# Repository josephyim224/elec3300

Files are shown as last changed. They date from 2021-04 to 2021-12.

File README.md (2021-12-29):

# Elec3300

This project builds an omni wheel car with a bluetooth remote controller. The omni wheel robot is based on STM32F103 with DRV8801 as motor driver. The controller is based on STM8S003.

## Car

### PCB Design

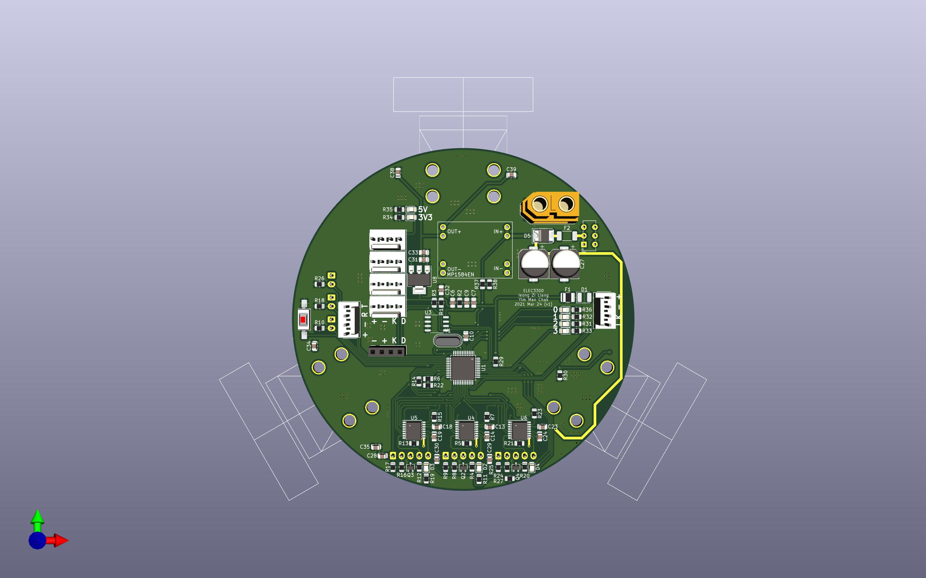
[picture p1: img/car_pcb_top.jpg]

*Car PCB Top View*

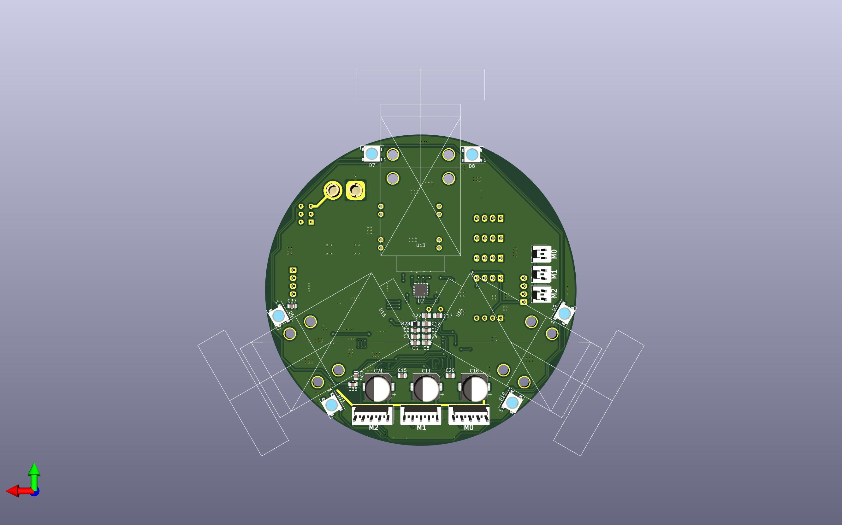
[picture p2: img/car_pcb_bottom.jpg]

*Car PCB Bottom View*

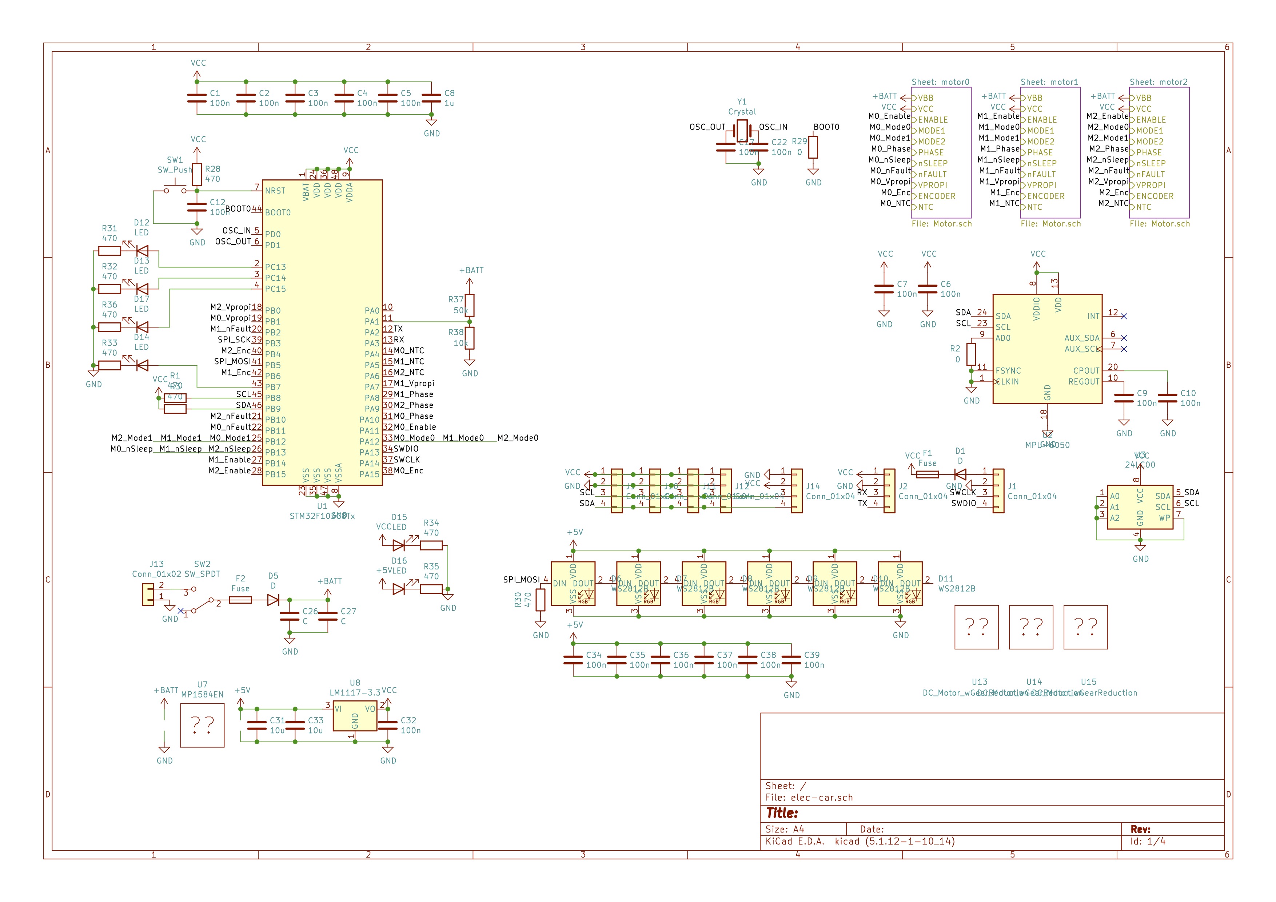
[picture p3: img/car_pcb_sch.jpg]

*see [schematic.pdf](car_hw/output/schematic.pdf)*

### 3D Print Components

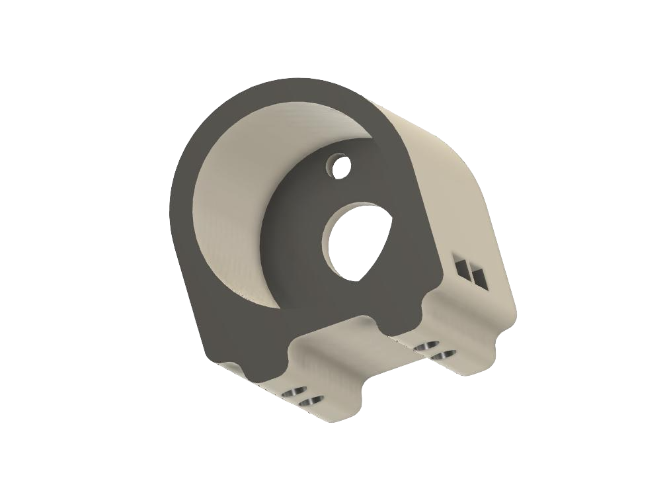
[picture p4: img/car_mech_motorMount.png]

*Car Motor Mount*

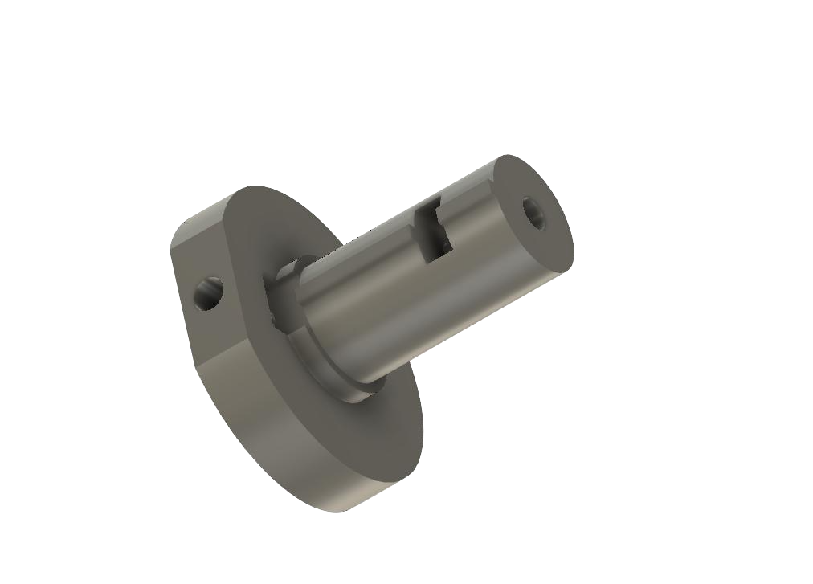
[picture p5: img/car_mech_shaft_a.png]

*Car Shaft A*

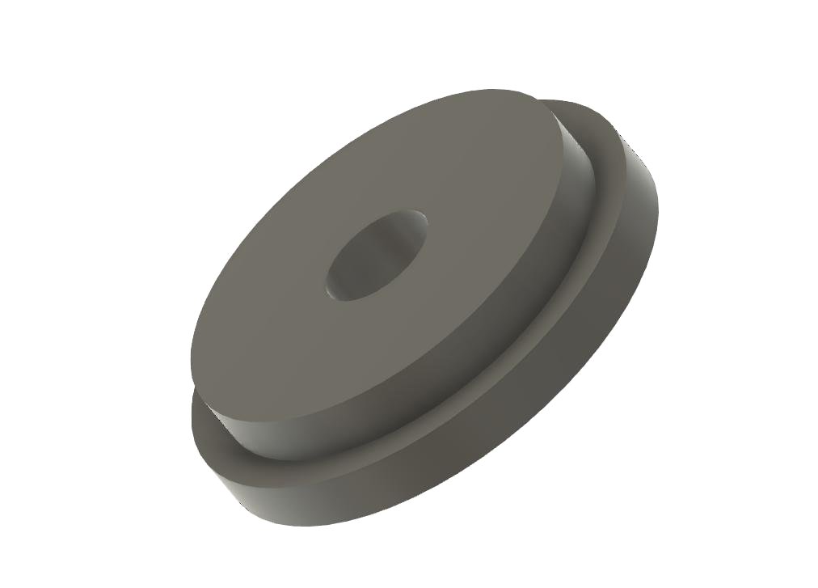
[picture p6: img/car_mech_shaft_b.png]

*Car Shaft B*

### Software

- Use STM32CubeIDE
- Refer to `/car_sw`

## Remote

### PCB Design

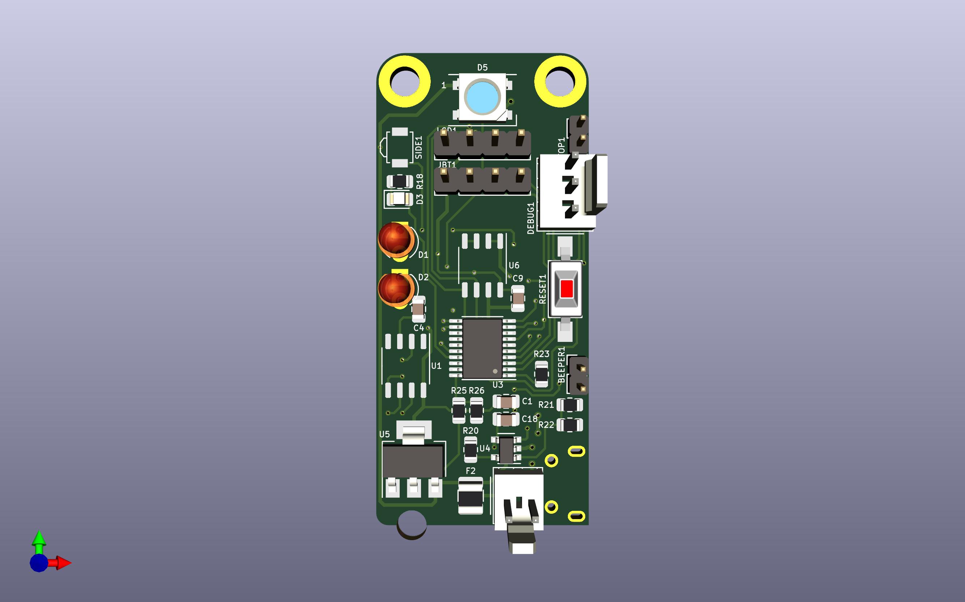
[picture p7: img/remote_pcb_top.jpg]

*Remote PCB Top View*

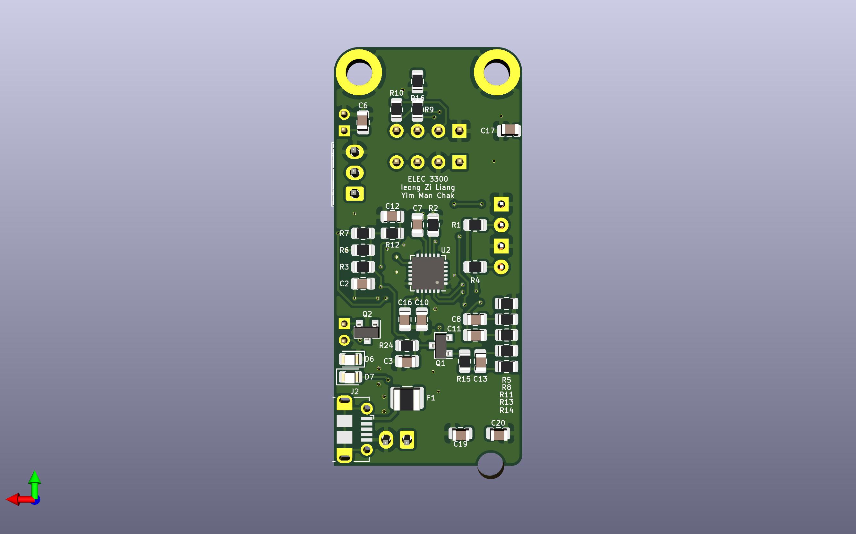
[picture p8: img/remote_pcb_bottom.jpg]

*Remote PCB Bottom View*

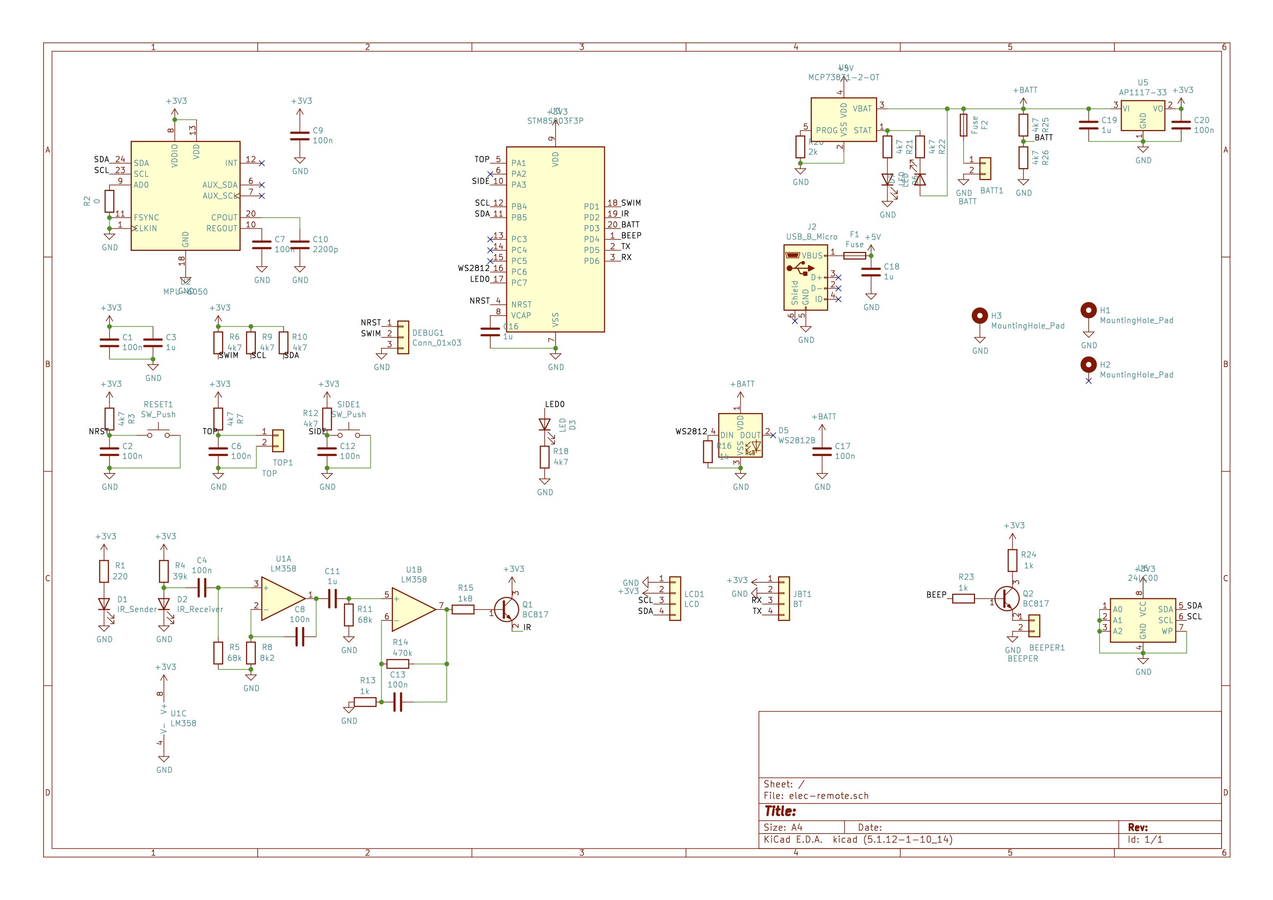
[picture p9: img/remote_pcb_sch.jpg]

*see [schematic.pdf](remote_hw/output/schematic.pdf)*

### 3D Print Components

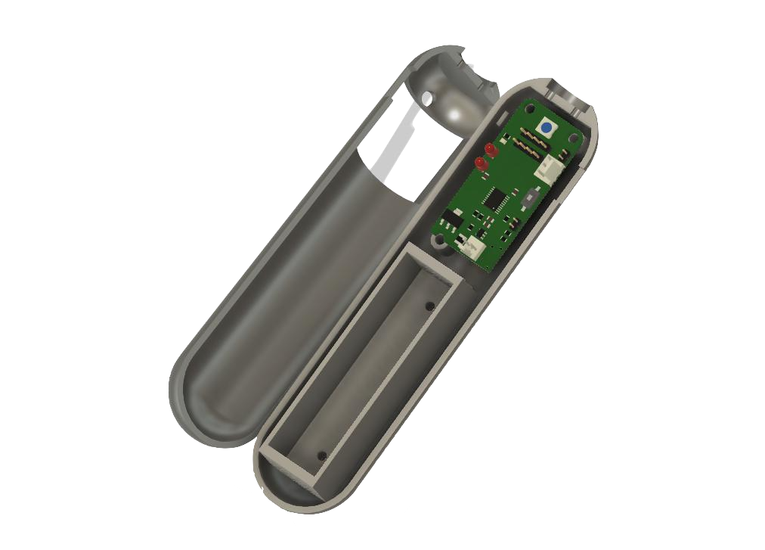
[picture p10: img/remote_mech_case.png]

*Remote Case*

### Software

Setup:
1. `sudo apt-get install libusb-1.0-0-dev sdcc -y`
1. Get [stm8flash](https://github.com/vdudouyt/stm8flash)
1. Run `bash ./flash.sh` to compile and flash program

Reference: [Getting started with STM8 Development Tools on GNU/LINUX](https://www.codementor.io/@hbendali/)getting-started-with-stm8-development-tools-on-gnu-linux-zu59yo35x

Template: [stsw-stm8069](https://my.st.com/content/my_st_com/en/products/embedded-software/mcu-mpu-embedded-software/stm8-embedded-software/stsw-stm8069.html)

Library: [stm8s-sdcc](https://github.com/stecman/stm8s-sdcc)

## Final Deliverables
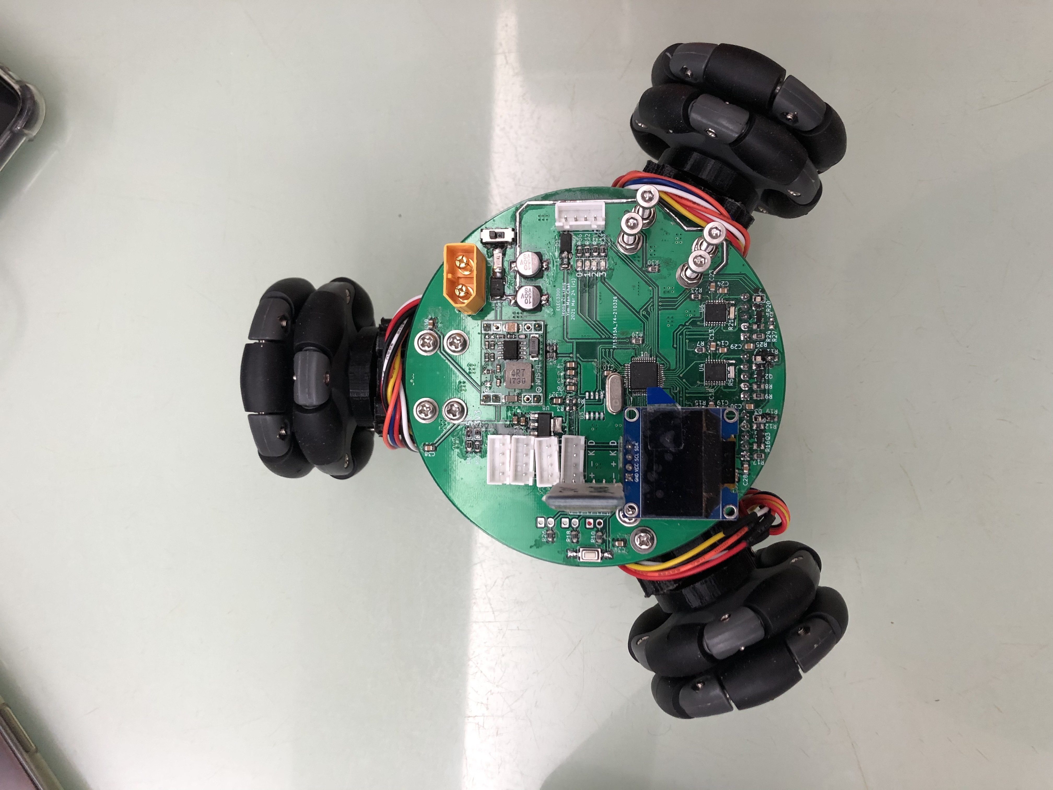
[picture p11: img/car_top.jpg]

*Car Top*

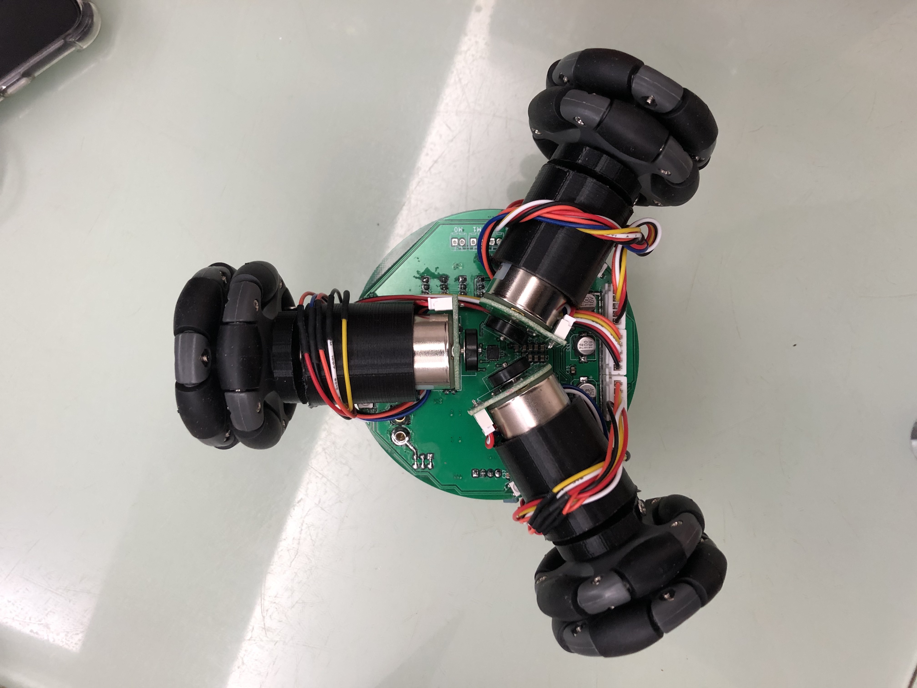
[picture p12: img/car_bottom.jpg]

*Car Bottom*

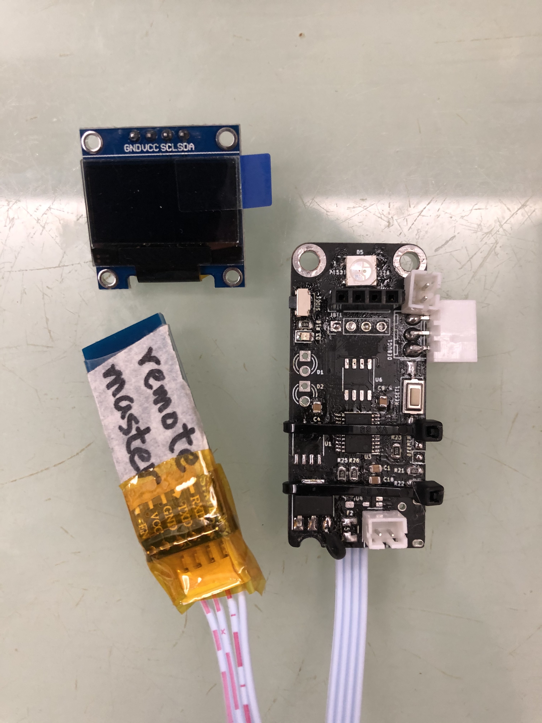
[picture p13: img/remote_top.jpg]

*Remote Top*

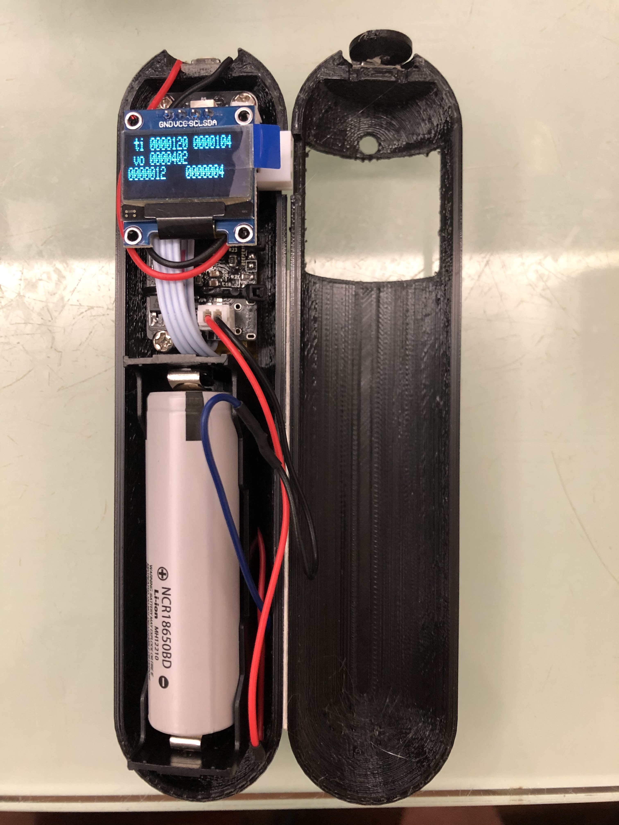
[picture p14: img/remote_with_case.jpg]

*Remote With Case*

## Progress
| urgency | difficulty | task | description | done? |
| --- | --- | --- | --- | --- |
| - | - | design pcb | | v |
| - | - | solder pcb | | v |
| - | - | mech design | | car(v), remote(v) |
| 0 | 0 | button | button | remote(v) | |
| 0 | 0 | led | led display | car(v), remote(v) |
| 1 | 1 | motor driver | (car) pwm & direction control | v |
| 1 | 2 | uart | communicate | car(v), remote(v) |
| 1 | 2 | i2c | communicate | car(v hardware), remote(v software) |
| 1 | 3 | mpu6050 (i2c) | port and simplify Adafruit version | car(v), remote(v) |
| 2 | 4 | ssd1306 lcd (i2c) | display line and text | car(v), remote(v) |
| 3 | 2 | ws2812b RGB led | display R/G/B | car(v), remote(x) |
| 4 | 1 | vibration motor | (remote) pwm output | x |
| 4 | 2 | 24c02 eeprom (i2c) | read and write data | x |
| 4 | ? | encoder | (car) encoder counter | v |
| 5 | 4 | gy530 TOF (i2c) | get distance | x |

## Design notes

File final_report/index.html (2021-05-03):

ELEC 3300 Final Project

Title : Reinventing remote robot with 3D input

Group: 10

Members Name | Ieong, Zi Liang Jason | Yim Man Chak
Members Email | zljieong@ust.hk | mcyim@ust.hk

Project Summary

Proposal Presentation

Proposal Presentation Video (https://youtu.be/K2rHprsLhMI)

Project Final Presentation

Project Final Demo and Presentation Video (https://youtu.be/Ji7nnWsCJ6Y)

Photos

Remote | Car
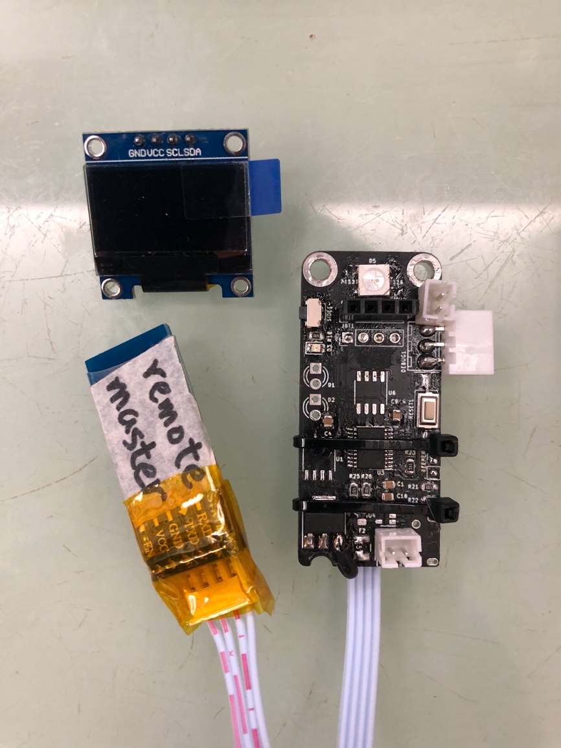
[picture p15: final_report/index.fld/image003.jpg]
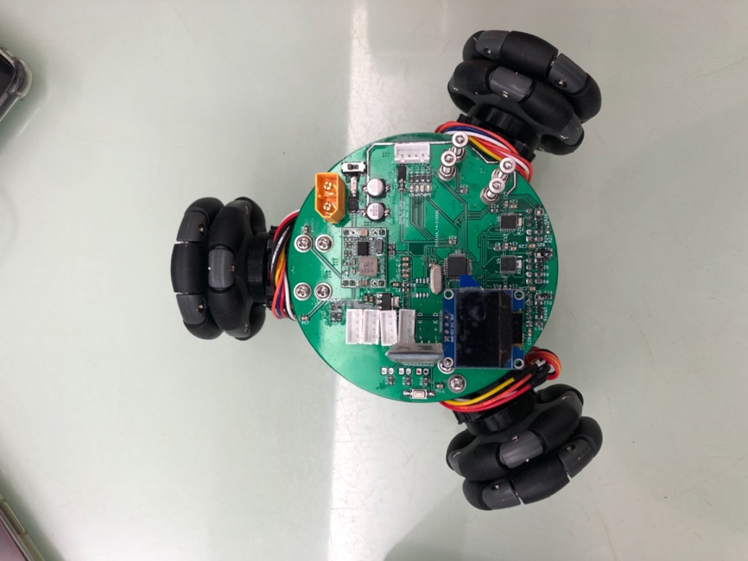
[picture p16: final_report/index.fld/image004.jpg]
A picture containing toy, indoor Description automatically generated
 | 
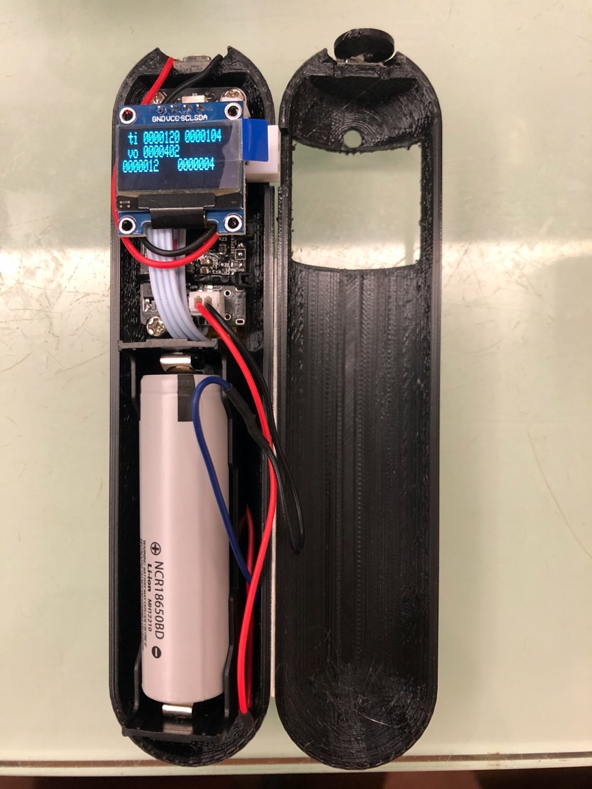
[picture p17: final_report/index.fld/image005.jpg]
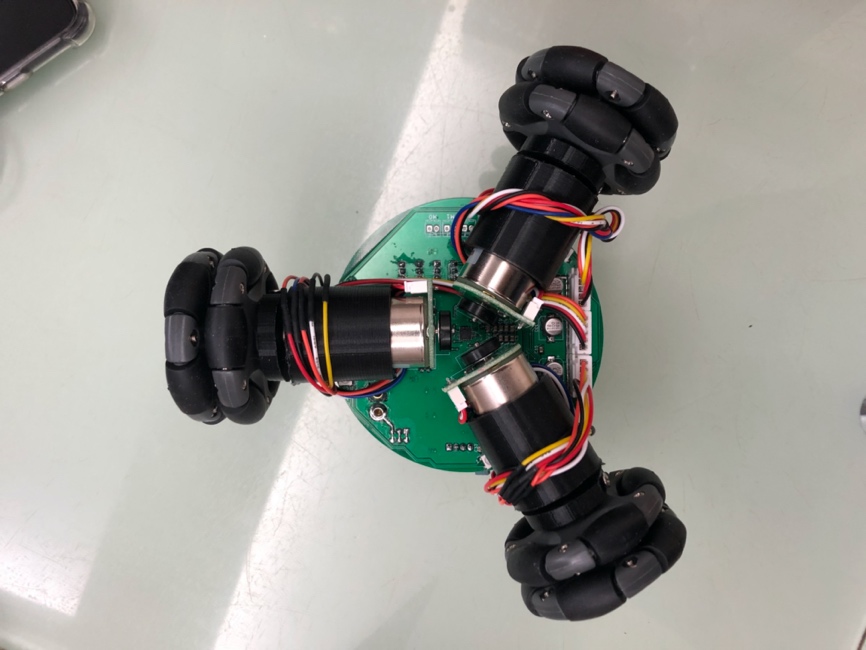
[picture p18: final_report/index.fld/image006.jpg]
A picture containing indoor, toy Description automatically generated
 | 

Remote Simulation Video

Car IOC

GitHub Repo (https://github.com/josephyim224/elec3300)

Project.zip

Folder list:

a. car_hw

b. car_sw

c. car_mech

d. remote_hw

e. remote_sw

f. remote_mech

g. datasheet

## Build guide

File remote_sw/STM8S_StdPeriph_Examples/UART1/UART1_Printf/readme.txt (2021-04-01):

/** @page UART1_Printf Retarget the C library printf function to the UART1

  @verbatim
  ******************** (C)COPYRIGHT 2014 STMicroelectronics *******************
  * @file    UART1/UART1_Printf/readme.txt 
  * @author  MCD Application Team
  * @version V2.0.4
  * @date    26-April-2018
  * @brief   Description of the UART1 retarget C library Example.
  ******************************************************************************
  *
  * Licensed under MCD-ST Liberty SW License Agreement V2, (the "License");
  * You may not use this file except in compliance with the License.
  * You may obtain a copy of the License at:
  *
  *        http://www.st.com/software_license_agreement_liberty_v2
  *
  * Unless required by applicable law or agreed to in writing, software 
  * distributed under the License is distributed on an "AS IS" BASIS, 
  * WITHOUT WARRANTIES OR CONDITIONS OF ANY KIND, either express or implied.
  * See the License for the specific language governing permissions and
  * limitations under the License.
  *
  ******************************************************************************
  @endverbatim

  @par Example description
  This example shows how to retarget the C library printf/getchar functions to the
  UART1. 
  This implementation output the printf message on the Hyperterminal using UART1 
  and keep waiting a character to be entered by the user.

  The UART1 is configured as follows:
    - BaudRate = 115200 baud  
    - Word Length = 8 Bits
    - One Stop Bit
    - No parity
    - Receive and transmit enabled
    - UART1 Clock disabled
 
  @par Directory contents

  - UART1\UART1_Printf\main.c           Main file containing the "main" function
  - UART1\UART1_Printf\stm8s_conf.h     Library Configuration file
  - UART1\UART1_Printf\stm8s_it.c       Interrupt routines source
  - UART1\UART1_Printf\stm8s_it.h       Interrupt routines declaration

  @par Hardware and Software environment

  - This example runs on STM8S High density and Low density devices and on STM8A
    High density devices.  
      
  - This example has been tested with STMicroelectronics STM8/128-EVAL evaluation 
    board and can be easily tailored to any other development board.

  - STM8/128-EVAL Set-up
     - Connect a null-modem female/female RS232 cable between the DB9 connector 
       CN13 and PC serial port.  

     - Hyperterminal configuration:
       - Word Length = 8 Bits
       - One Stop Bit
       - No parity
       - BaudRate = 115200 baud
       - flow control: None 

  @par How to use it ?

  In order to make the program work, you must do the following :

  - Copy all source files from this example folder to the template folder under
    Project\Template
  - Open your preferred toolchain 
  - Rebuild all files and load your image into target memory
  - Run the example
  
  @note
  - High-Density STM8A devices are the STM8AF52xx STM8AF6269/8x/Ax,
    STM8AF51xx, and STM8AF6169/7x/8x/9x/Ax microcontrollers where the Flash memory
    density ranges between 32 to 128 Kbytes
  - Medium-Density STM8A devices are the STM8AF622x/4x, STM8AF6266/68,
    STM8AF612x/4x, and STM8AF6166/68 microcontrollers where the Flash memory 
    density ranges between 8 to 32 Kbytes
  - High-Density STM8S devices are the STM8S207xx, STM8S007 and STM8S208xx microcontrollers
    where the Flash memory density ranges between 32 to 128 Kbytes.
  - Medium-Density STM8S devices are the STM8S105x and STM8S005 microcontrollers
    where the Flash memory density ranges between 16 to 32-Kbytes.
  - Low-Density STM8S devices are the STM8S103xx, STM8S003, STM8S001 and STM8S903xx microcontrollers
    where the Flash density is 8 Kbytes.
      
 * <h3><center>&copy; COPYRIGHT STMicroelectronics</center></h3>
 */

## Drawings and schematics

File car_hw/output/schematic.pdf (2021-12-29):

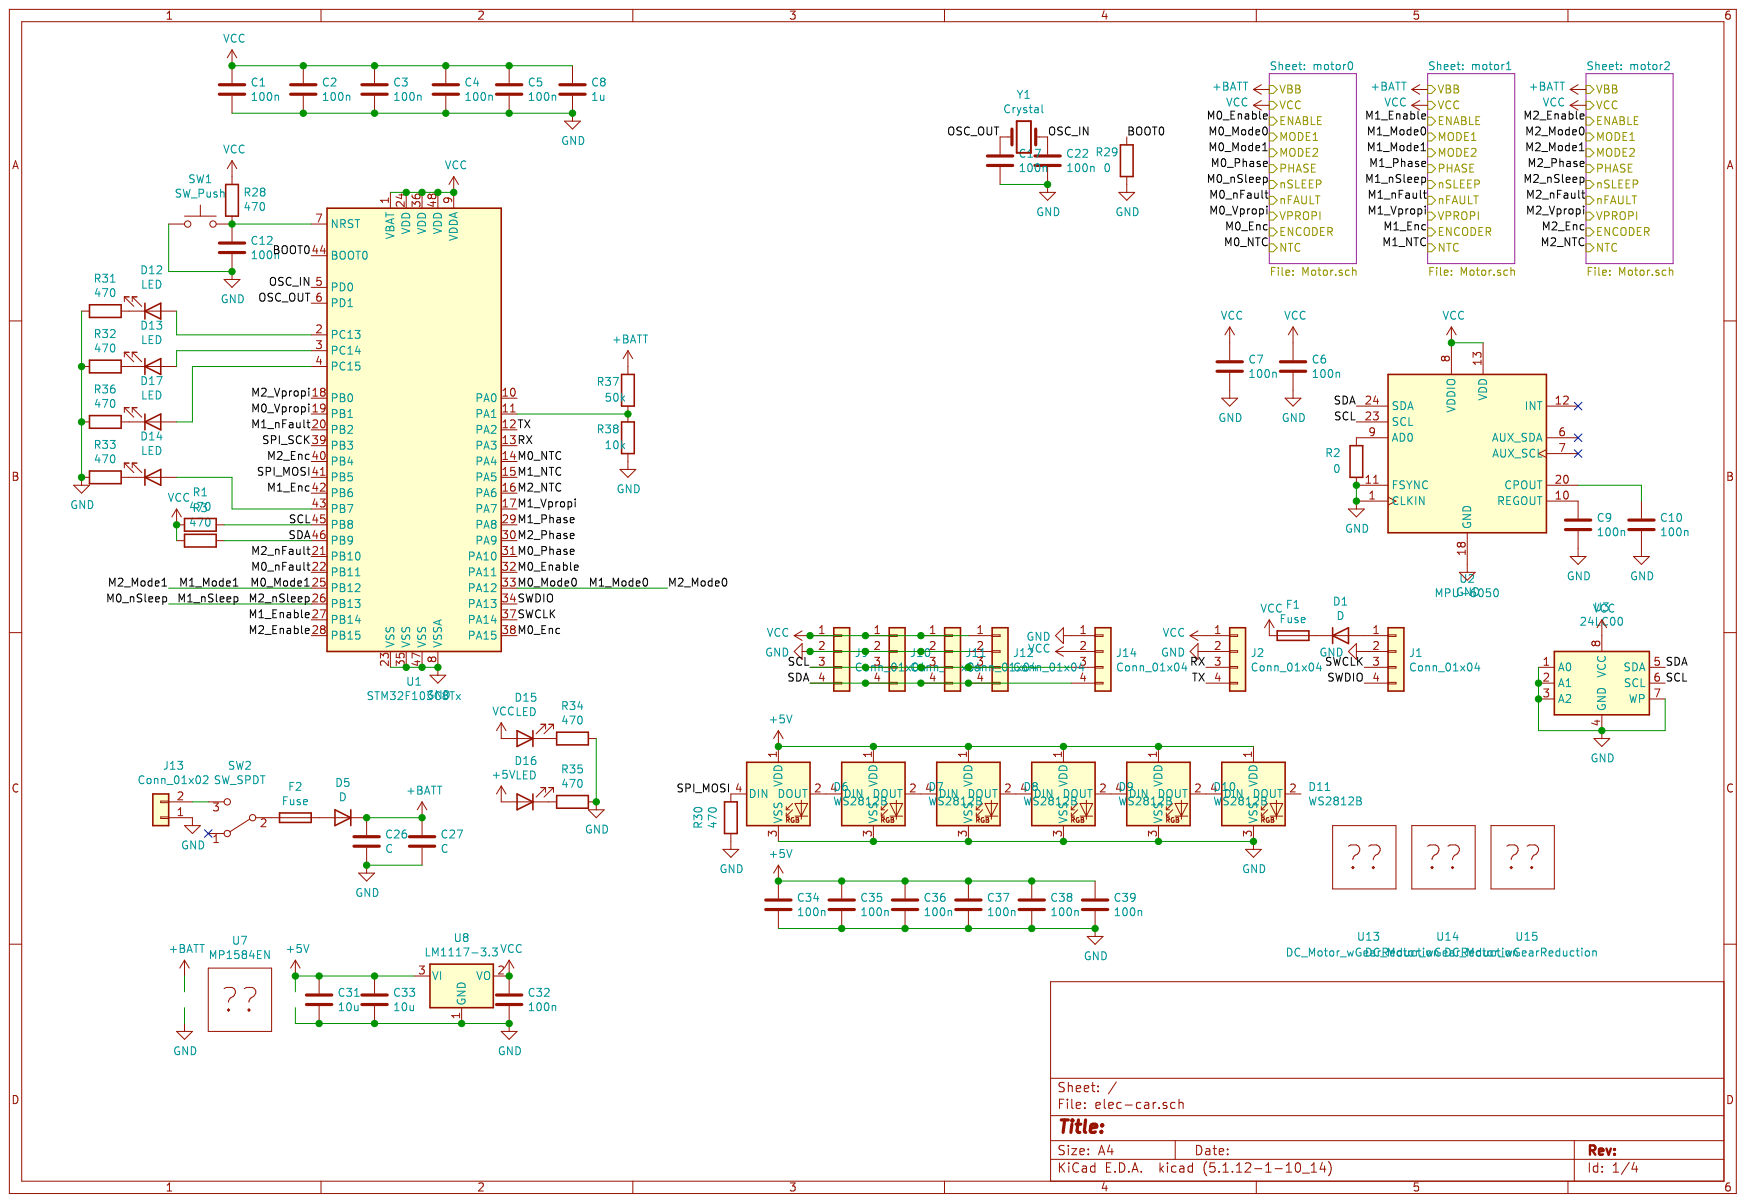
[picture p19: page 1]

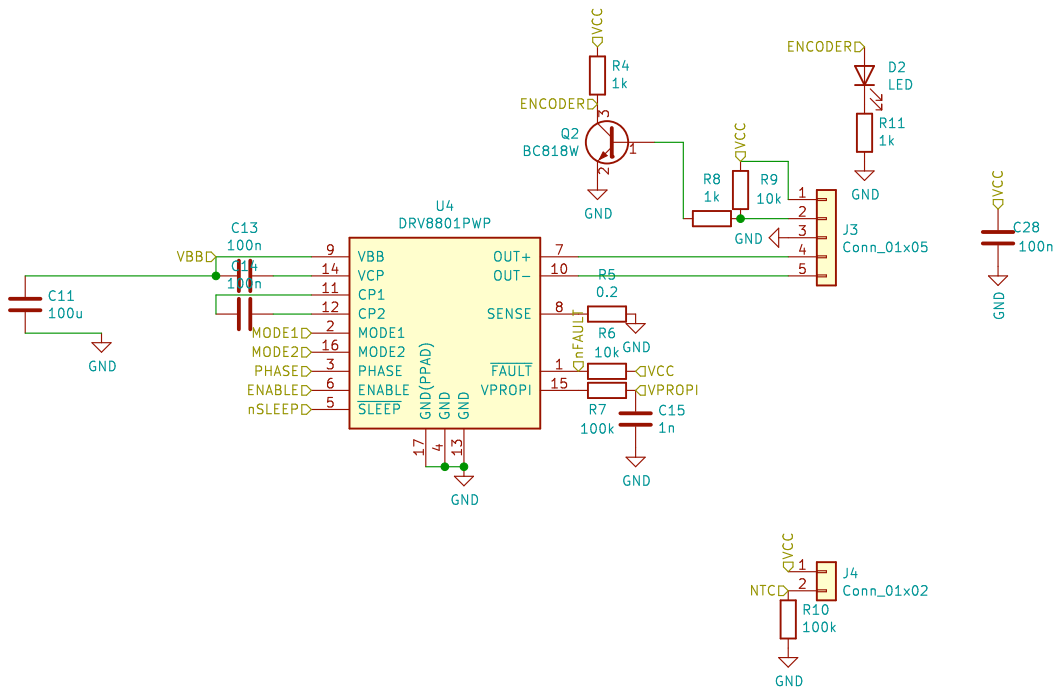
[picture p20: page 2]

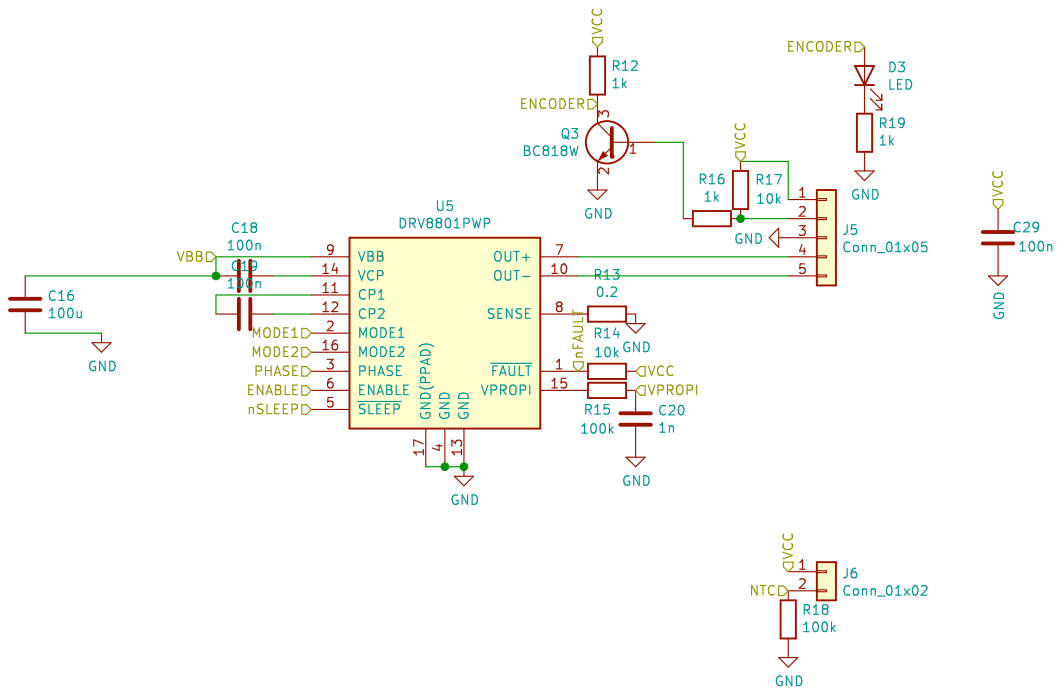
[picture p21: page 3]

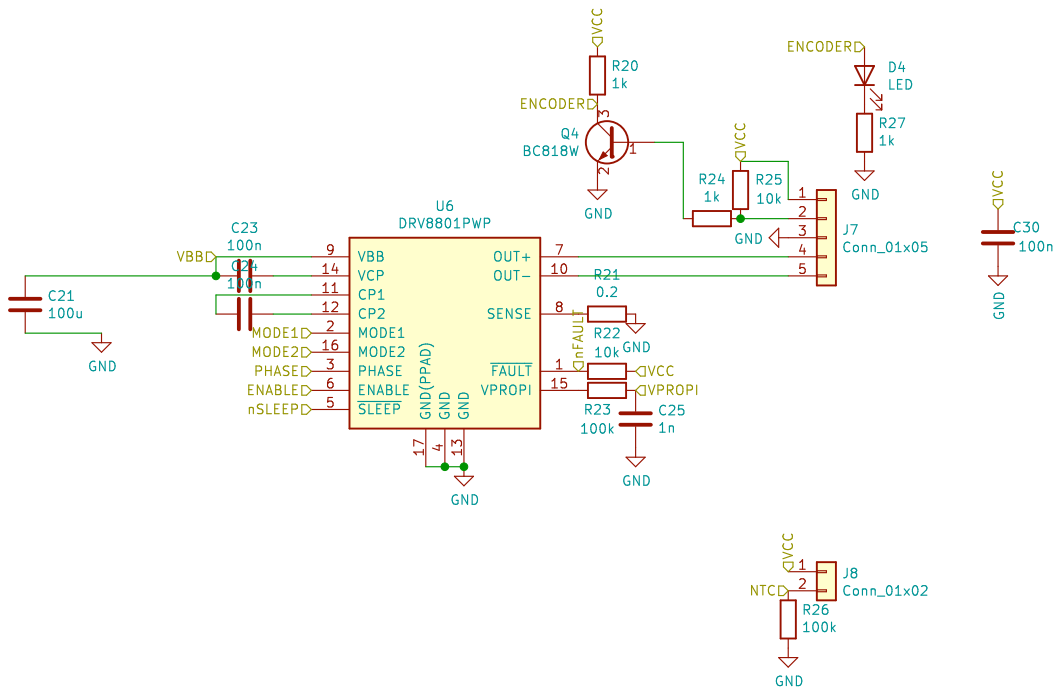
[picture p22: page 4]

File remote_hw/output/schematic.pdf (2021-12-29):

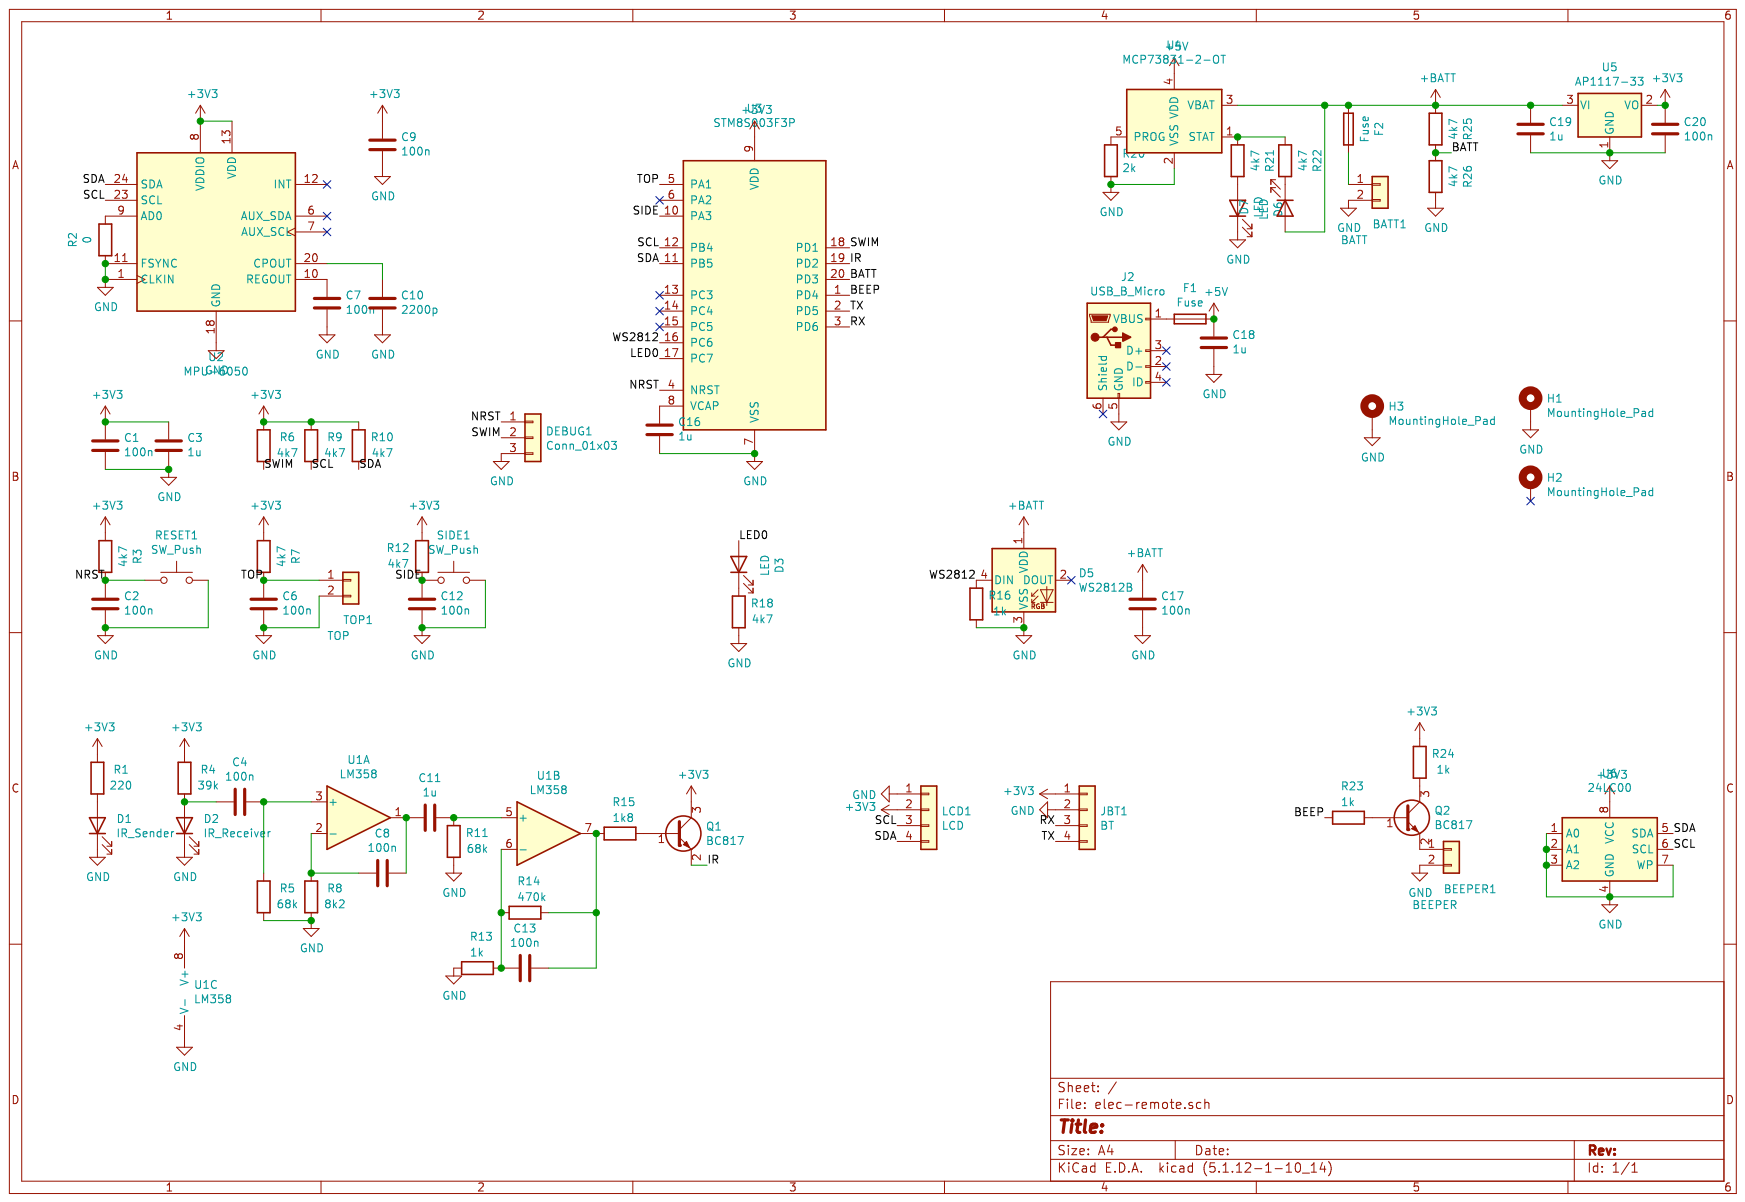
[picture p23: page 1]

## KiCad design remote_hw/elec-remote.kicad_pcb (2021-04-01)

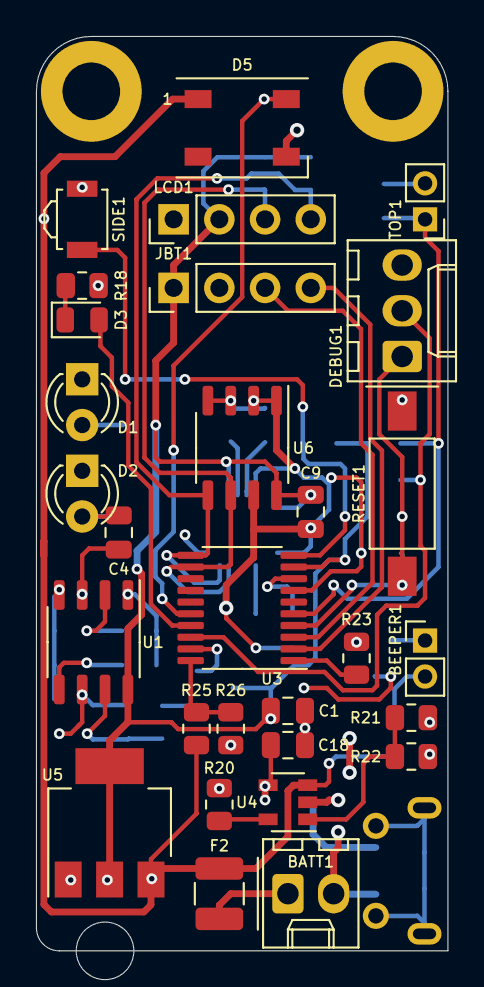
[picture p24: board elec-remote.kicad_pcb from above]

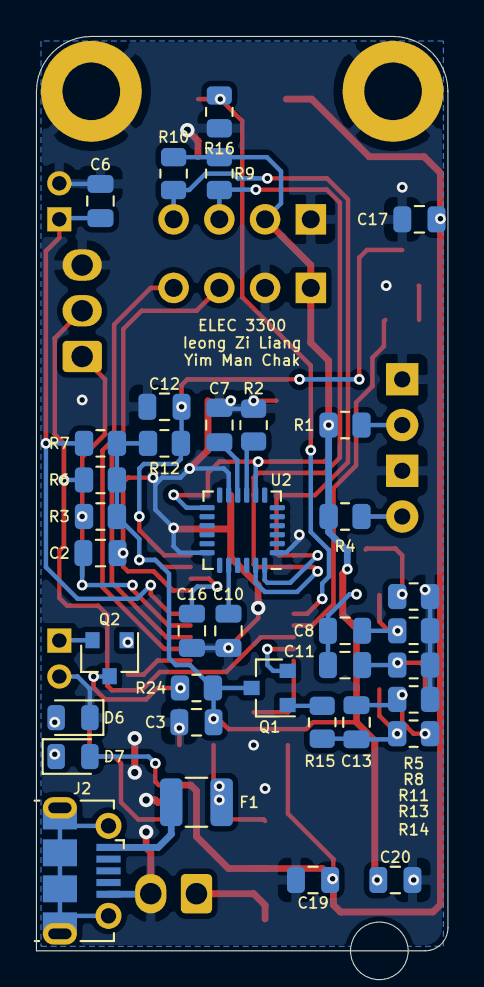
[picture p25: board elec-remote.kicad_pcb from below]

Board: 2 copper layers, 22.9 x 50.8 mm, 69 parts (37 on the bottom side), 40 nets.

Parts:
BATT1: BATT; Molex_KK-254_AE-6410-02A_1x02_P2.54mm_Vertical
BEEPER1: BEEPER; PinHeader_1x02_P2.00mm_Vertical
C1, C2, C4, C6, C7, C8, C9, C12, C13, C17, C20: 100n; C_0805_2012Metric
C3, C11, C16, C18, C19: 1u; C_0805_2012Metric
C10: 2200p; C_0805_2012Metric
D1: IR_Sender; LED_D3.0mm
D2: IR_Receiver; LED_D3.0mm
D3, D6, D7: LED; LED_0805_2012Metric
D5: WS2812B; LED_WS2812B_PLCC4_5.0x5.0mm_P3.2mm
DEBUG1: Conn_01x03; Molex_KK-254_AE-6410-03A_1x03_P2.54mm_Vertical
F1, F2: Fuse; Fuse_1210_3225Metric
H1, H3: MountingHole_Pad; MountingHole_3.2mm_M3_DIN965_Pad
H2: MountingHole_Pad; MountingHole_3.2mm_M3
J2: USB_B_Micro; USB_Micro-B_Molex-105017-0001
JBT1: BT; PinHeader_1x04_P2.54mm_Vertical
LCD1: LCD; PinHeader_1x04_P2.54mm_Vertical
Q1, Q2: BC817; SOT-23
R1: 220; R_0805_2012Metric
R2: 0; R_0805_2012Metric
R3, R6, R7, R9, R10, R12, R18, R21, R22, R25, R26: 4k7; R_0805_2012Metric
R4: 39k; R_0805_2012Metric
R5, R11: 68k; R_0805_2012Metric
R8: 8k2; R_0805_2012Metric
R13, R16, R23, R24: 1k; R_0805_2012Metric
R14: 470k; R_0805_2012Metric
R15: 1k8; R_0805_2012Metric
R20: 2k; R_0805_2012Metric
RESET1: SW_Push; SW_SPST_FSMSM
SIDE1: SW_Push; SW_SPST_B3U-3000P
TOP1: TOP; PinHeader_1x02_P2.00mm_Vertical
U1: LM358; SOP-8_3.9x4.9mm_P1.27mm
U2: MPU-6050; InvenSense_QFN-24_4x4mm_P0.5mm
U3: STM8S003F3P; TSSOP-20_4.4x6.5mm_P0.65mm
U4: MCP73831-2-OT; SOT-23-5
U5: AP1117-33; SOT-223-3_TabPin2
U6: 24LC00; SOP-8_3.9x4.9mm_P1.27mm

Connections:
+3V3: C1.2, C3.2, C9.2, C20.1, JBT1.1, LCD1.2, Q1.3, R1.2, R3.2, R4.2, R6.2, R7.2, R9.2, R10.2, R12.2, R24.2, U1.8, U2.8, U2.13, U3.9, U5.2, U6.8
+5V: C18.2, F1.1, U4.4
+BATT: C17.2, C19.1, D5.1, D7.2, F2.2, R25.2, U4.3, U5.3
/BATT: R25.1, R26.2, U3.20
/BEEP: R23.2, U3.1
/IR: Q1.2, U3.19
/LED0: D3.2, U3.17
/NRST: C2.2, DEBUG1.1, R3.1, RESET1.1, U3.4
/RX: JBT1.3, U3.3
/SCL: LCD1.3, R9.1, U2.23, U3.12, U6.6
/SDA: LCD1.4, R10.1, U2.24, U3.11, U6.5
/SIDE: C12.2, R12.1, SIDE1.1, U3.10
/SWIM: DEBUG1.2, R6.1, U3.18
/TOP: C6.2, R7.1, TOP1.1, U3.5
/TX: JBT1.4, U3.2
/WS2812: D5.4, R16.2, U3.16
GND: BATT1.2, BEEPER1.2, C1.1, C2.1, C3.1, C6.1, C7.1, C9.1, C10.1, C12.1, C16.1, C17.1, C18.1, C19.2, C20.2, D1.1, D2.1, D5.3, D6.1, DEBUG1.3, H1.1, H3.1, J2.5, JBT1.2, LCD1.1, R2.2, R5.1, R8.1, R11.1, R13.2, R16.1, R18.1, R20.2, R26.1, RESET1.2, SIDE1.2, TOP1.2, U1.4, U2.1, U2.11, U2.18, U3.7, U4.2, U5.1, U6.1, U6.2, U6.3, U6.4, U6.7
unnamed: BATT1.1, F2.1
unnamed: BEEPER1.1, Q2.2
unnamed: C4.1, R5.2, U1.3
unnamed: C4.2, D2.2, R4.1
unnamed: C7.2, U2.10
unnamed: C8.2, R8.2, U1.2
unnamed: C10.2, U2.20
unnamed: C11.1, R11.2, U1.5
unnamed: C8.1, C11.2, U1.1
unnamed: C13.1, R14.1, R15.2, U1.7
unnamed: C13.2, R13.1, R14.2, U1.6
unnamed: C16.2, U3.8
unnamed: D1.2, R1.1
unnamed: D3.1, R18.2
unnamed: D6.2, R21.1
unnamed: D7.1, R22.1
unnamed: F1.2, J2.1
unnamed: Q1.1, R15.1
unnamed: Q2.1, R23.1
unnamed: Q2.3, R24.1
unnamed: R2.1, U2.9
unnamed: R20.1, U4.5
unnamed: R21.2, R22.2, U4.1

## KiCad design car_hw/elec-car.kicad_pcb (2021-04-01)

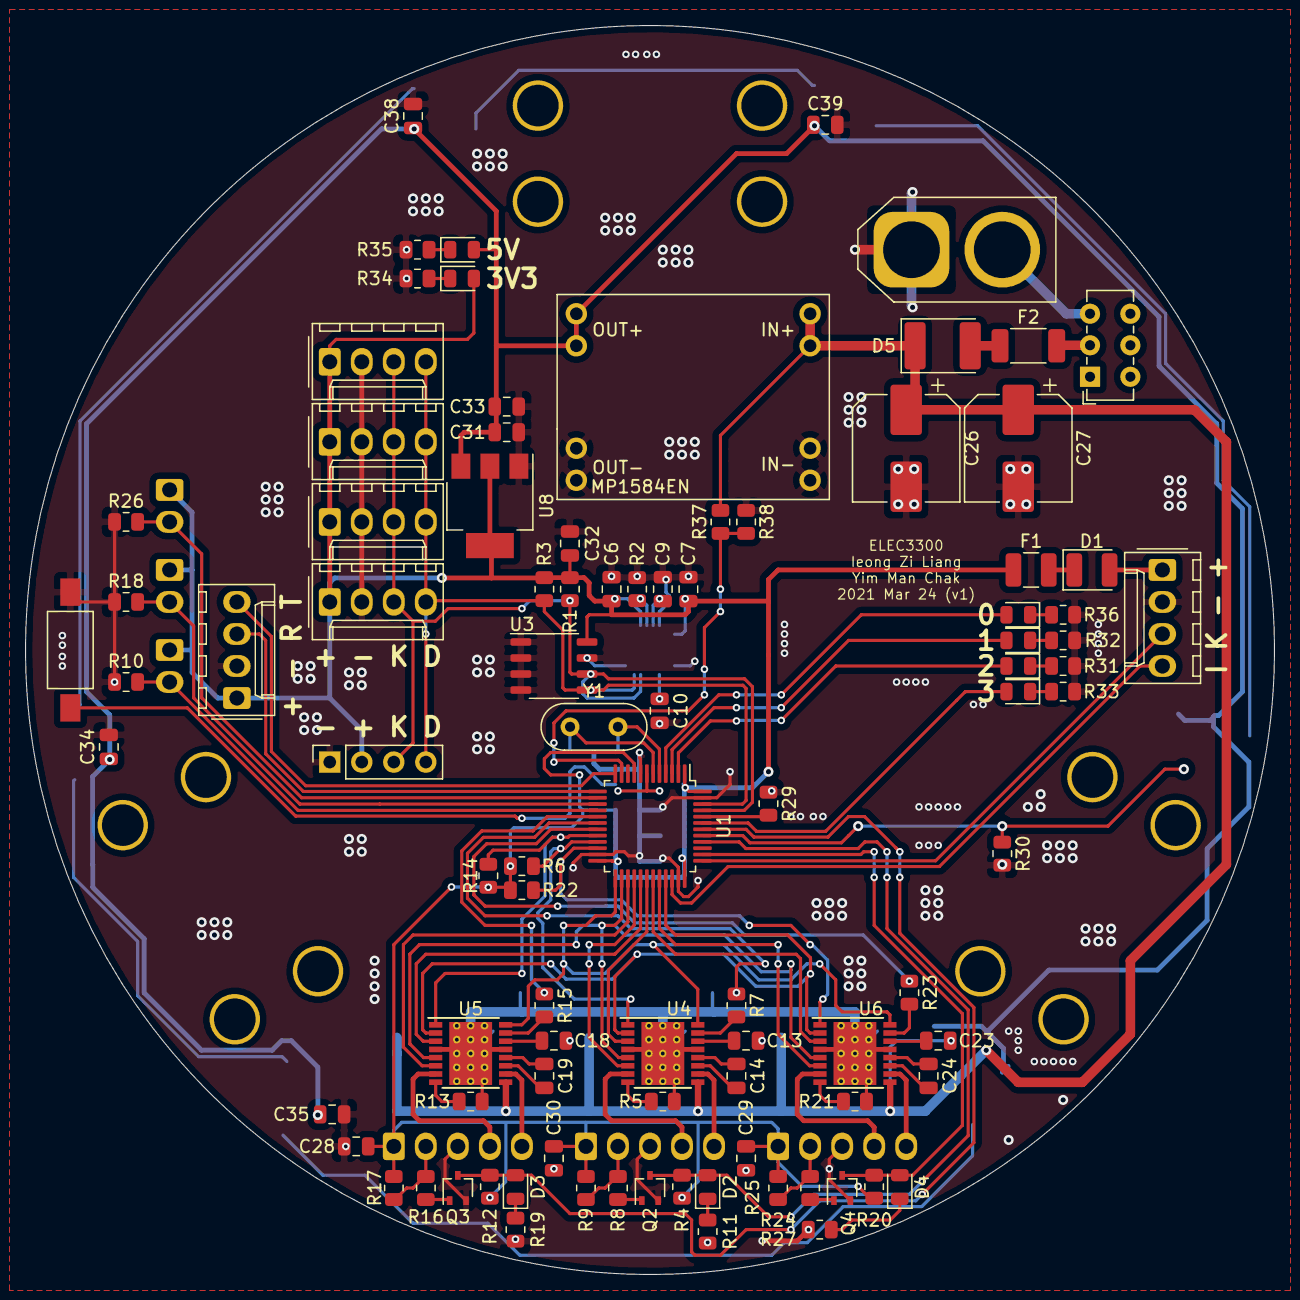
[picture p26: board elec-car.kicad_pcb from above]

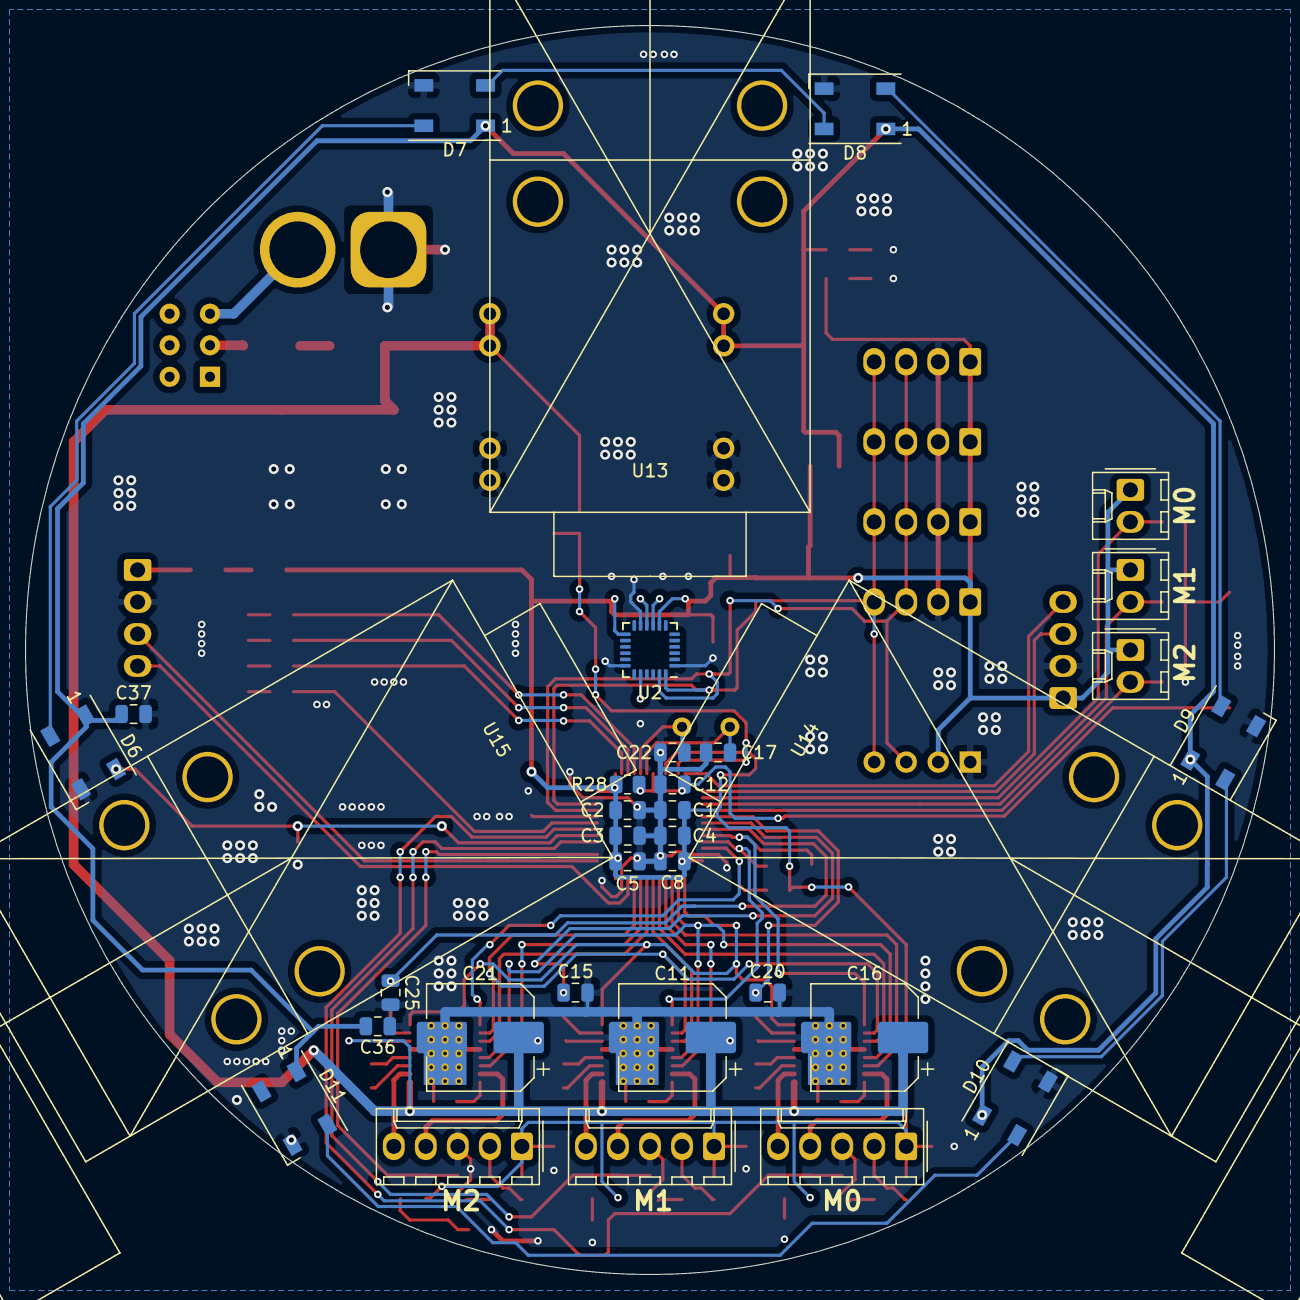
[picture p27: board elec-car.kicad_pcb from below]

Board: 2 copper layers, 99.1 x 99.1 mm, 127 parts (34 on the bottom side), 90 nets.

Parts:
C1, C2, C3, C4, C5, C6, C7, C9, C10, C12, C13, C14, C17, C18, C19, C22, C23, C24, C28, C29, C30, C32, C34, C35, C36, C37, C38, C39: 100n; C_0805_2012Metric
C8: 1u; C_0805_2012Metric
C11, C16, C21: 100u; CP_Elec_8x5.4
C15, C20, C25: 1n; C_0805_2012Metric
C26, C27: C; CP_Elec_8x5.4
C31, C33: 10u; C_0805_2012Metric
D1: D; D_1210_3225Metric
D2, D3, D4, D12, D13, D14, D15, D16, D17: LED; LED_0805_2012Metric
D5: D; D_2114_3652Metric
D6, D7, D8, D9, D10, D11: WS2812B; LED_WS2812B_PLCC4_5.0x5.0mm_P3.2mm
F1: Fuse; Fuse_1210_3225Metric
F2: Fuse; Fuse_2010_5025Metric
J1, J2, J9, J10, J11, J12: Conn_01x04; Molex_KK-254_AE-6410-04A_1x04_P2.54mm_Vertical
J3, J5, J7: Conn_01x05; Molex_KK-254_AE-6410-05A_1x05_P2.54mm_Vertical
J4, J6, J8: Conn_01x02; Molex_KK-254_AE-6410-02A_1x02_P2.54mm_Vertical
J13: Conn_01x02; AMASS_XT60-F_1x02_P7.20mm_Vertical
J14: Conn_01x04; PinSocket_1x04_P2.54mm_Vertical
Q2, Q3, Q4: BC818W; SOT-323_SC-70
R1, R3, R28, R30, R31, R32, R33, R34, R35, R36: 470; R_0805_2012Metric
R2, R29: 0; R_0805_2012Metric
R4, R8, R11, R12, R16, R19, R20, R24, R27: 1k; R_0805_2012Metric
R5, R13, R21: 0.2; R_0805_2012Metric
R6, R9, R14, R17, R22, R25, R38: 10k; R_0805_2012Metric
R7, R10, R15, R18, R23, R26: 100k; R_0805_2012Metric
R37: 50k; R_0805_2012Metric
SW1: SW_Push; SW_SPST_FSMSM
SW2: SW_SPDT; SW_E-Switch_EG1271_DPDT
U1: STM32F103C8Tx; LQFP-48_7x7mm_P0.5mm
U2: MPU-6050; InvenSense_QFN-24_4x4mm_P0.5mm
U3: 24LC00; SOP-8_3.9x4.9mm_P1.27mm
U4, U5, U6: DRV8801PWP; HTSSOP-16-1EP_4.4x5mm_P0.65mm_EP3.4x5mm_Mask3x3mm_ThermalVi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
U7: MP1584EN
U8: LM1117-3.3; SOT-223-3_TabPin2
U13, U14, U15: DC_Motor_wGearReduction
Y1: Crystal; Crystal_HC52-6mm_Vertical

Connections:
+5V: C31.1, C33.1, C34.1, C35.1, C36.1, C37.1, C38.1, C39.1, D6.1, D7.1, D8.1, D9.1, D10.1, D11.1, D16.2, U7.5, U7.6, U8.3
+BATT: C11.1, C13.2, C16.1, C18.2, C21.1, C23.2, C26.1, C27.1, D5.1, R37.2, U4.9, U5.9, U6.9, U7.1, U7.2
/BOOT0: R29.2, U1.44
/M0_Enable: U1.32, U6.6
/M0_Enc: D4.2, Q4.3, R20.1, U1.38
/M0_Mode0: U1.33, U4.2, U5.2, U6.2
/M0_Mode1: U1.25, U4.16, U5.16, U6.16
/M0_NTC: J8.2, R26.2, U1.14
/M0_Phase: U1.31, U6.3
/M0_Vpropi: C25.1, R23.1, U1.19
/M0_nFault: R22.2, U1.22, U6.1
/M0_nSleep: U1.26, U4.5, U5.5, U6.5
/M1_Enable: U1.27, U5.6
/M1_Enc: D3.2, Q3.3, R12.1, U1.42
/M1_NTC: J6.2, R18.2, U1.15
/M1_Phase: U1.29, U5.3
/M1_Vpropi: C20.1, R15.1, U1.17
/M1_nFault: R14.2, U1.20, U5.1
/M2_Enable: U1.28, U4.6
/M2_Enc: D2.2, Q2.3, R4.1, U1.40
/M2_NTC: J4.2, R10.2, U1.16
/M2_Phase: U1.30, U4.3
/M2_Vpropi: C15.1, R7.1, U1.18
/M2_nFault: R6.2, U1.21, U4.1
/OSC_IN: C22.1, U1.5, Y1.2
/OSC_OUT: C17.1, U1.6, Y1.1
/RX: J2.3, U1.13
/SCL: J9.3, J10.3, J11.3, J12.3, J14.3, R1.1, U1.45, U2.23, U3.6
/SDA: J9.4, J10.4, J11.4, J12.4, J14.4, R3.1, U1.46, U2.24, U3.5
/SPI_MOSI: D6.4, R30.1, U1.41
/SWCLK: J1.3, U1.37
/SWDIO: J1.4, U1.34
/TX: J2.4, U1.12
GND: C1.2, C2.2, C3.2, C4.2, C5.2, C6.2, C7.2, C8.2, C9.2, C10.2, C11.2, C12.2, C15.2, C16.2, C17.2, C20.2, C21.2, C22.2, C25.2, C26.2, C27.2, C28.1, C29.1, C30.1, C31.2, C32.2, C33.2, C34.2, C35.2, C36.2, C37.2, C38.2, C39.2, D6.3, D7.3, D8.3, D9.3, D10.3, D11.3, J1.2, J2.2, J3.3, J5.3, J7.3, J9.2, J10.2, J11.2, J12.2, J13.1, J14.1, Q2.2, Q3.2, Q4.2, R2.1, R5.1, R10.1, R11.1, R13.1, R18.1, R19.1, R21.1, R26.1, R27.1, R29.1, R30.2, R31.1, R32.1, R33.1, R34.1, R35.1, R36.1, R38.1, SW1.1, U1.8, U1.23, U1.35, U1.47, U2.1, U2.11, U2.18, U3.1, U3.2, U3.3, U3.4, U3.7, U4.4, U4.13, U4.17, U5.4, U5.13, U5.17, U6.4, U6.13, U6.17, U7.3, U7.4, U7.7, U7.8, U8.1
unnamed: C9.1, U2.10
unnamed: C10.1, U2.20
unnamed: C12.1, R28.1, SW1.2, U1.7
unnamed: C13.1, U4.14
unnamed: C14.1, U4.12
unnamed: C14.2, U4.11
unnamed: C18.1, U5.14
unnamed: C19.1, U5.12
unnamed: C19.2, U5.11
unnamed: C23.1, U6.14
unnamed: C24.1, U6.12
unnamed: C24.2, U6.11
unnamed: D1.1, F1.1
unnamed: D1.2, J1.1
unnamed: D2.1, R11.2
unnamed: D3.1, R19.2
unnamed: D4.1, R27.2
unnamed: D5.2, F2.1
unnamed: D6.2, D7.4
unnamed: D7.2, D8.4
unnamed: D8.2, D9.4
unnamed: D10.2, D11.4
unnamed: D9.2, D10.4
unnamed: D12.1, R31.2
unnamed: D12.2, U1.2
unnamed: D13.1, R32.2
unnamed: D13.2, U1.3
unnamed: D14.1, R33.2
unnamed: D14.2, U1.43
unnamed: D15.1, R34.2
unnamed: D16.1, R35.2
unnamed: D17.1, R36.2
unnamed: D17.2, U1.4
unnamed: F2.2, SW2.2
unnamed: J3.2, R8.1, R9.1
unnamed: J3.4, U4.7
unnamed: J3.5, U4.10
unnamed: J5.2, R16.1, R17.1
unnamed: J5.4, U5.7
unnamed: J5.5, U5.10
unnamed: J7.2, R24.1, R25.1
unnamed: J7.4, U6.7
unnamed: J7.5, U6.10
unnamed: J13.2, SW2.3
unnamed: Q2.1, R8.2
unnamed: Q3.1, R16.2
unnamed: Q4.1, R24.2
unnamed: R2.2, U2.9
unnamed: R5.2, U4.8
unnamed: R7.2, U4.15
unnamed: R13.2, U5.8
unnamed: R15.2, U5.15
unnamed: R21.2, U6.8
unnamed: R23.2, U6.15
unnamed: R37.1, R38.2, U1.11
VCC: C1.1, C2.1, C3.1, C4.1, C5.1, C6.1, C7.1, C8.1, C28.2, C29.2, C30.2, C32.1, D15.2, F1.2, J2.1, J3.1, J4.1, J5.1, J6.1, J7.1, J8.1, J9.1, J10.1, J11.1, J12.1, J14.2, R1.2, R3.2, R4.2, R6.1, R9.2, R12.2, R14.1, R17.2, R20.2, R22.1, R25.2, R28.2, U1.1, U1.9, U1.24, U1.36, U1.48, U2.8, U2.13, U3.8, U8.2

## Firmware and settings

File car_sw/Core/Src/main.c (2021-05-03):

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
/* Includes ------------------------------------------------------------------*/
#include "main.h"
#include "adc.h"
#include "i2c.h"
#include "tim.h"
#include "usart.h"
#include "gpio.h"
#include "math.h"

/* USER CODE BEGIN Includes */
#include <stdio.h>
#include "SSD1306.h"
#include "WS2812B.h"
#include "MPU6050.h"
#include "motion.h"

/* USER CODE END Includes */


/* USER CODE BEGIN PV */
uint8_t RGBs[3 * 6];
/* USER CODE END PV */

void SystemClock_Config(void);
/* USER CODE BEGIN 0 */
struct MPU6050 m_mpu6050_readData(uint8_t *buffer) {
	// get raw readings

	int16_t rawAccX = buffer[0] << 8 | buffer[1];
	int16_t rawAccY = buffer[2] << 8 | buffer[3];
	int16_t rawAccZ = buffer[4] << 8 | buffer[5];

	int16_t rawGyroX = buffer[8] << 8 | buffer[9];
	int16_t rawGyroY = buffer[10] << 8 | buffer[11];
	int16_t rawGyroZ = buffer[12] << 8 | buffer[13];

	float accel_scale = 16384;
	// setup range dependent scaling
	float accX = ((float) rawAccX) / accel_scale;
	float accY = ((float) rawAccY) / accel_scale;
	float accZ = ((float) rawAccZ) / accel_scale;

	float gyro_scale = 65.5;

	float gyroX = ((float) rawGyroX) / gyro_scale;
	float gyroY = ((float) rawGyroY) / gyro_scale;
	float gyroZ = ((float) rawGyroZ) / gyro_scale;

	struct MPU6050 received_mpu;
	received_mpu.accX = accX;
	received_mpu.accY = accY;
	received_mpu.accZ = accZ;
	received_mpu.gyroX = gyroX;
	received_mpu.gyroY = gyroY;
	received_mpu.gyroZ = gyroZ;

	return received_mpu;
}

/* USER CODE END 0 */

/**
 * @brief  The application entry point.
 * @retval int
 */
int main(void) {
	/* USER CODE BEGIN 1 */
	RGBs[0] = 0;
	RGBs[1] = 0;
	RGBs[2] = 255;

	RGBs[3] = 0;
	RGBs[4] = 255;
	RGBs[5] = 0;

	RGBs[6] = 255;
	RGBs[7] = 0;
	RGBs[8] = 0;

	/* USER CODE END 1 */

	/* MCU Configuration--------------------------------------------------------*/

	/* Reset of all peripherals, Initializes the Flash interface and the Systick. */
	HAL_Init();

	/* Configure the system clock */
	SystemClock_Config();

	/* Initialize all configured peripherals */
	MX_GPIO_Init();
	MX_ADC1_Init();
	MX_I2C1_Init();
	MX_TIM1_Init();
	MX_USART2_UART_Init();
	MX_TIM2_Init();
	MX_TIM3_Init();
	MX_TIM4_Init();
	/* USER CODE BEGIN 2 */

	ssd1306_begin(&hi2c1);

	mpu6050_begin(&hi2c1);
	drv8801_begin(&htim1, &htim2, &htim4, &htim3);

	uint8_t grb[] = { 0xff, 0x00, 0x00 };
	uint32_t last_tick = HAL_GetTick();

	/* motor test code */
	if (0) {
		setPower(0, 1000);
		setPower(1, 1000);
		setPower(2, 1000);

		{
			setDirection(0, 0);
			setDirection(1, 0);
			setDirection(2, 0);
			HAL_Delay(2000);
		}
		{
			setDirection(0, 1);
			setDirection(1, 1);
			setDirection(2, 1);
			HAL_Delay(2000);
		}

		{
			setPower(0, 0);
			setDirection(1, 0);
			setDirection(2, 1);
			HAL_Delay(2000);
		}
		{
			setPower(0, 0);
			setDirection(1, 1);
			setDirection(2, 0);
			HAL_Delay(2000);
		}
	}

	setDirection(0, 0);
	setDirection(1, 1);

//	setPower(0, 700);
//	setPower(1, 700);
//	setPower(2, 0);

	/* USER CODE END 2 */

	/* Infinite loop */
	/* USER CODE BEGIN WHILE */
	int last_x_count = 0;
	uint8_t MPU_real_buffer[14];
	int count = 0;
//	struct MPU6050 received_mpu;

//	float AccErrorX = 0;
//	float AccErrorY = 0;
//	float GyroErrorX = 0;
//	float GyroErrorY = 0;
//	float GyroErrorZ = 0;

	float AccErrorX = -2.51f;
	float AccErrorY = -4.57f;
	float GyroErrorX = 0.87f;
	float GyroErrorY = 2.89f;
	float GyroErrorZ = -4.93;

	float gyroAngleX = 0; // deg/s * s = deg
	float gyroAngleY = 0;

	float roll = 0;
	float pitch = 0;
	float yaw = 0;

	float recorded_roll = 0;
	float recorded_pitch = 0;
	float recorded_yaw = 0;

	uint8_t UART2_rxBuffer[3];
	uint32_t last_RGB_tick = 0;

	uint8_t color_count = 0;
	while (1) {
		HAL_GPIO_TogglePin(LED0_GPIO_Port, LED0_Pin);
//		HAL_GPIO_TogglePin(LED1_GPIO_Port, LED1_Pin);
//		HAL_GPIO_TogglePin(LED2_GPIO_Port, LED2_Pin);
//		HAL_GPIO_TogglePin(LED3_GPIO_Port, LED3_Pin);

//		writeRGB(grb);
//		writeRGB(grb);
//		writeRGB(grb);
//		writeRGB(grb);
//		writeRGB(grb);
//		writeRGB(grb);

//		grb[2] += 16;
//		grb[1] += 16;

//		mpu6050_readData();
//
		uint8_t c[20];

		clearDisplay();

		uint8_t UART2_rx;
		static uint8_t uart2_count = 0;

//		mpu6050_readData();
		uint8_t calibrate_error = 1;

//		static int encoder_counter = -1;
//
//		if (HAL_UART_Receive(&huart2, &UART2_rxBuffer, 1, 100) == HAL_OK) {
//			drawString(0, 24, &UART2_rxBuffer, 1, SSD1306_WHITE, SSD1306_BLACK);
//			switch (UART2_rxBuffer) {
//			case 'W': {
//				move(MOTION_FORWARD);
//				break;
//			}
//			case 'A': {
//				move(MOTION_TRANSLATE_LEFT);
//				break;
//			}
//			case 'S': {
//				move(MOTION_BACKWARD);
//				break;
//			}
//			case 'D': {
//				move(MOTION_TRANSLATE_RIGHT);
//				break;
//			}
//			case 'Q': {
//				move(MOTION_ROTATE_LEFT);
//				break;
//			}
//			case 'E': {
//				move(MOTION_ROTATE_RIGHT);
//				break;
//			}
//			case 'K': {
//				move(MOTION_STOP);
//				break;
//			}
//
//			}
//		}

		uint8_t MPU_buffer[43];
		if (HAL_UART_Receive(&huart2, MPU_buffer, 43, 1000) == HAL_OK) {
			uint8_t i = 0;
			for (; i < 43 - 16; ++i) {
				if (MPU_buffer[i] == '1' && MPU_buffer[i + 1] == '2'
						&& MPU_buffer[i + 2] == '3') {
					struct MPU6050 received_mpu = m_mpu6050_readData(
							MPU_buffer + i + 3);
					uint8_t is_pressing = MPU_buffer[i + 3 + 14];
					static uint8_t was_pressing = 0;

					sprintf(c, "pres %u     ", is_pressing);
					drawString(60, 8, c, 9, SSD1306_WHITE, SSD1306_BLACK);
//					sprintf(c, "%f      ", received_mpu.accX);
//					drawString(0, 0, c, 9, SSD1306_WHITE, SSD1306_BLACK);
//					sprintf(c, "%f      ", received_mpu.accY);
//					drawString(0, 8, c, 9, SSD1306_WHITE, SSD1306_BLACK);
//					sprintf(c, "%f      ", received_mpu.accZ);
//					drawString(0, 16, c, 9, SSD1306_WHITE, SSD1306_BLACK);

					uint8_t calibrate_error = 0;

					//source: https://howtomechatronics.com/tutorials/arduino/arduino-and-mpu6050-accelerometer-and-gyroscope-tutorial/

					if (calibrate_error) {
						if (count < 200) {
							AccErrorX =
									AccErrorX
											+ ((atan(
													(received_mpu.accY)
															/ sqrt(
																	pow(
																			(received_mpu.accX),
																			2)
																			+ pow(
																					(received_mpu.accZ),
																					2)))
													* 180 / M_PI));
							AccErrorY =
									AccErrorY
											+ ((atan(
													-1 * (received_mpu.accX)
															/ sqrt(
																	pow(
																			(received_mpu.accY),
																			2)
																			+ pow(
																					(received_mpu.accZ),
																					2)))
													* 180 / M_PI));
							GyroErrorX = GyroErrorX + received_mpu.gyroX;
							GyroErrorY = GyroErrorY + received_mpu.gyroY;
							GyroErrorZ = GyroErrorZ + received_mpu.gyroZ;
							count++;

							sprintf(c, "%f      ", AccErrorX / count);
							drawString(0, 0, c, 9, SSD1306_WHITE,
							SSD1306_BLACK);
							sprintf(c, "%f      ", AccErrorY / count);
							drawString(0, 8, c, 9, SSD1306_WHITE,
							SSD1306_BLACK);
							sprintf(c, "%f      ", GyroErrorX / count);
							drawString(0, 16, c, 9, SSD1306_WHITE,
							SSD1306_BLACK);
							sprintf(c, "%f      ", GyroErrorY / count);
							drawString(0, 24, c, 9, SSD1306_WHITE,
							SSD1306_BLACK);
							sprintf(c, "%f      ", GyroErrorZ / count);
							drawString(60, 0, c, 9, SSD1306_WHITE,
							SSD1306_BLACK);
							sprintf(c, "%d      ", count);
							drawString(60, 8, c, 9, SSD1306_WHITE,
							SSD1306_BLACK);
							if (count == 200) {
								HAL_Delay(1000000);
							}
						}
					} else {
						float accAngleX =
								((atan(
										(received_mpu.accY)
												/ sqrt(
														pow((received_mpu.accX),
																2)
																+ pow(
																		(received_mpu.accZ),
																		2)))
										* 180 / M_PI)) - AccErrorX;

						float accAngleY =
								((atan(
										-1 * (received_mpu.accX)
												/ sqrt(
														pow((received_mpu.accY),
																2)
																+ pow(
																		(received_mpu.accZ),
																		2)))
										* 180 / M_PI)) - AccErrorY;

						float GyroX = received_mpu.gyroX - GyroErrorX;
						float GyroY = received_mpu.gyroY - GyroErrorY;
						float GyroZ = received_mpu.gyroZ - GyroErrorZ;
						// Currently the raw values are in degrees per seconds, deg/s, so we need to multiply by sendonds (s) to get the angle in degrees
						static uint32_t last_MPU_tick = 0;
						uint32_t MPU_tick = HAL_GetTick();
						float elapsedTime = ((float) (MPU_tick - last_MPU_tick))
								/ 1000.0f;
						if (last_MPU_tick != 0) {

							gyroAngleX = gyroAngleX + GyroX * elapsedTime; // deg/s * s = deg
							gyroAngleY = gyroAngleY + GyroY * elapsedTime;
							yaw = yaw + GyroZ * elapsedTime;
							roll = 0.96 * gyroAngleX + 0.04 * accAngleX;
							pitch = 0.96 * gyroAngleY + 0.04 * accAngleY;
						}
						last_MPU_tick = MPU_tick;

						if (is_pressing && !was_pressing) {
							recorded_roll = roll;
							recorded_pitch = pitch;
							recorded_yaw = yaw;
						}
						if (is_pressing) {
							float dr = roll - recorded_roll;
							float dp = pitch - recorded_pitch;
							float dy = yaw - recorded_yaw;

							sprintf(c, "r:%f      ", dr);
							drawString(0, 0, c, 9, SSD1306_WHITE,
							SSD1306_BLACK);
							sprintf(c, "p:%f      ", dp);
							drawString(0, 8, c, 9, SSD1306_WHITE,
							SSD1306_BLACK);
							sprintf(c, "y:%f      ", dy);
							drawString(0, 16, c, 9, SSD1306_WHITE,
							SSD1306_BLACK);

							if ((fabs(dr) - fabs(dp) > 20)
									&& (fabs(dr) - fabs(dy) > 20)) {
								if (dr > 0) {
									move(MOTION_FORWARD);
									sprintf(c, "forward  ");
									drawString(60, 0, c, 9, SSD1306_WHITE,
									SSD1306_BLACK);

									if (HAL_GetTick() - last_RGB_tick > 100) {
										last_RGB_tick = HAL_GetTick();
										uint8_t c[] = { 255, 0, 0 };
										for (uint8_t i = 0; i < 3 * 6; i += 3) {
											writeRGB(c);
										}
									}
								} else {
									move(MOTION_BACKWARD);
									sprintf(c, "back  ");
									drawString(60, 0, c, 9, SSD1306_WHITE,
									SSD1306_BLACK);

									if (HAL_GetTick() - last_RGB_tick > 100) {
										last_RGB_tick = HAL_GetTick();
										uint8_t c[] = { 0, 255, 0 };
										for (uint8_t i = 0; i < 3 * 6; i += 3) {
											writeRGB(c);
										}
									}
								}
							} else if ((fabs(dp) - fabs(dr) > 50)
									&& (fabs(dp) - fabs(dy) > 50)) {
								if (dp > 0) {
									move(MOTION_ROTATE_LEFT);
									sprintf(c, "left  ");
									drawString(60, 0, c, 9, SSD1306_WHITE,
									SSD1306_BLACK);

									if (HAL_GetTick() - last_RGB_tick > 20) {
										color_count = (color_count + 17) % 18;
										last_RGB_tick = HAL_GetTick();
										uint8_t R[] = { 255, 0, 0 };
										uint8_t G[] = { 0, 255, 0 };
										uint8_t B[] = { 0, 0, 255 };
										uint8_t C[] = { 0, 0, 0 };

										for (uint8_t i = 0; i < 3 * 6; i += 3) {
											if ((color_count % 6) * 3 == i
													|| (color_count + 1 % 6) * 3
															== i) {
												if (color_count < 6) {
													writeRGB(R);
												} else if (color_count < 12) {
													writeRGB(G);
												} else if (color_count < 18) {
													writeRGB(B);
												}

											} else {
												writeRGB(C);
												//												writeRGB(R);
											}
										}

									}

								} else {
									sprintf(c, "right  ");
									drawString(60, 0, c, 9, SSD1306_WHITE,
									SSD1306_BLACK);
									move(MOTION_ROTATE_RIGHT);

									if (HAL_GetTick() - last_RGB_tick > 20) {
										color_count = (color_count + 1) % 18;
										last_RGB_tick = HAL_GetTick();
										uint8_t R[] = { 255, 0, 0 };
										uint8_t G[] = { 0, 255, 0 };
										uint8_t B[] = { 0, 0, 255 };
										uint8_t C[] = { 0, 0, 0 };

										for (uint8_t i = 0; i < 3 * 6; i += 3) {
											if ((color_count % 6) * 3 == i
													|| (color_count + 1 % 6) * 3
															== i) {
												if (color_count < 6) {
													writeRGB(R);
												} else if (color_count < 12) {
													writeRGB(G);
												} else if (color_count < 18) {
													writeRGB(B);
												}

											} else {
												writeRGB(C);
											}
										}

									}
								}
							} else if ((fabs(dy) - fabs(dr) > 20)
									&& (fabs(dy) - fabs(dp) > 20)) {
								if (dr > 0) {
									sprintf(c, "T_L  ");
									drawString(60, 0, c, 9, SSD1306_WHITE,
									SSD1306_BLACK);
									move(MOTION_TRANSLATE_LEFT);

									if (HAL_GetTick() - last_RGB_tick > 100) {
										last_RGB_tick = HAL_GetTick();
										uint8_t c[] = { 255, 255, 0 };
										for (uint8_t i = 0; i < 3 * 6; i += 3) {
											writeRGB(c);
										}
									}
								} else {
									sprintf(c, "T_R  ");
									drawString(60, 0, c, 9, SSD1306_WHITE,
									SSD1306_BLACK);
									move(MOTION_TRANSLATE_RIGHT);

									if (HAL_GetTick() - last_RGB_tick > 100) {
										last_RGB_tick = HAL_GetTick();
										uint8_t c[] = { 0, 255, 255 };
										for (uint8_t i = 0; i < 3 * 6; i += 3) {
											writeRGB(c);
										}
									}
								}

							} else {
								move(MOTION_STOP);
//								if (HAL_GetTick() - last_RGB_tick > 20) {
//									last_RGB_tick = HAL_GetTick();
//
//									float smoothness_pts = 600;//larger=slower change in brightness
//
//									float gamma = 0.14; // affects the width of peak (more or less darkness)
//									float beta = 0.5; // shifts the gaussian to be symmetric
//									float ii = (last_RGB_tick / 10) % 600;
//									float pwm_val = 255.0*(exp(-(pow(((ii/smoothness_pts)-beta)/gamma,2.0))/2.0));
//
//									uint8_t c[] = { pwm_val, pwm_val, pwm_val };
//									for (uint8_t i = 0; i < 3 * 6; i += 3) {
//										writeRGB(c);
//									}
//								}
							}

						} else {
							move(MOTION_STOP);

							if (HAL_GetTick() - last_RGB_tick > 20) {
								last_RGB_tick = HAL_GetTick();

								float smoothness_pts = 600; //larger=slower change in brightness

								float gamma = 0.14; // affects the width of peak (more or less darkness)
								float beta = 0.5; // shifts the gaussian to be symmetric
								float ii = (last_RGB_tick / 10) % 600;
								float pwm_val = 255.0
										* (exp(
												-(pow(
														((ii / smoothness_pts)
																- beta) / gamma,
														2.0)) / 2.0));

								uint8_t c[] = { pwm_val, pwm_val, pwm_val };
								for (uint8_t i = 0; i < 3 * 6; i += 3) {
									writeRGB(c);
								}
							}

						}

						was_pressing = is_pressing;

						sprintf(c, "s:%f      ", MPU_tick / 1000.0f);
						drawString(60, 16, c, 9, SSD1306_WHITE,
						SSD1306_BLACK);

					}

					break;
				} else {
				}
			}
			if (i == 37) {
				sprintf(c, "Not OK!", i);
				drawString(0, 16, c, 9, SSD1306_WHITE, SSD1306_BLACK);
			}

		} else {
			sprintf(c, "no 37 buffer");
			drawString(0, 24, c, 9, SSD1306_WHITE, SSD1306_BLACK);
		}
		MotorUpdate();
		display();

		/* USER CODE END WHILE */

		/* USER CODE BEGIN 3 */
	}
	/* USER CODE END 3 */
}

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


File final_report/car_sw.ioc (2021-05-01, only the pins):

Mcu.UserName=STM32F103C8Tx
PB14.GPIO_Label=M1_ENABLE
PA6.GPIO_Label=M2_NTC
PB0.GPIO_Label=M2_VPROPI
PB6.GPIO_Label=M0_ENC
PB13.GPIO_Label=M_nSLEEP
PB11.Signal=GPIO_Input
PB13.Signal=GPIO_Output
PB15.Signal=TIM1_CH3N
PC15-OSC32_OUT.GPIO_Label=LED0
PD1-OSC_OUT.Signal=RCC_OSC_OUT
PA15.GPIO_Label=M1_ENC
PA12.Signal=GPIO_Output
PB6.Signal=S_TIM4_CH1
PB2.Signal=GPIO_Input
PB12.GPIO_Label=M_MODE1
PB1.GPIO_Label=M0_VPROPI
PA10.GPIO_Label=M0_PHASE
PB7.Signal=GPIO_Output
PA8.Signal=GPIO_Output
PB7.GPIO_Label=LED3
PB9.Signal=I2C1_SDA
PB1.Signal=ADCx_IN9
PA6.Signal=ADCx_IN6
PA10.Signal=GPIO_Output
PA15.Signal=S_TIM2_CH1_ETR
PB5.GPIO_Label=WS2812B
PC14-OSC32_IN.GPIO_Label=LED1
PA4.GPIO_Label=M0_NTC
PB4.Signal=S_TIM3_CH1
PA3.Signal=USART2_RX
PA9.GPIO_Label=M2_PHASE
PB11.GPIO_Label=M0_nFAULT
PC13-TAMPER-RTC.Signal=GPIO_Output
PA11.GPIO_Label=M0_ENABLE
PD0-OSC_IN.Signal=RCC_OSC_IN
PC14-OSC32_IN.Signal=GPIO_Output
PA12.GPIO_Label=M_MODE0
PA13.Signal=SYS_JTMS-SWDIO
PA8.GPIO_Label=M1_PHASE
PB10.GPIO_Label=M2_nFAULT
PA9.Signal=GPIO_Output
PC15-OSC32_OUT.Signal=GPIO_Output
PA1.Signal=ADCx_IN1
PB10.Signal=GPIO_Input
PB14.Signal=TIM1_CH2N
PA5.Signal=ADCx_IN5
PC13-TAMPER-RTC.GPIO_Label=LED2
PB4.GPIO_Label=M2_ENC
PB15.GPIO_Label=M2_ENABLE
PA1.GPIO_Label=BATT
PA2.Signal=USART2_TX
PA4.Signal=ADCx_IN4
PB5.Signal=GPIO_Output
PA7.GPIO_Label=M1_VPROPI
PA5.GPIO_Label=M1_NTC
PA11.Signal=S_TIM1_CH4
PA14.Signal=SYS_JTCK-SWCLK
PB2.GPIO_Label=M1_nFAULT
PB8.Signal=I2C1_SCL
PB0.Signal=ADCx_IN8
PB12.Signal=GPIO_Output
PA7.Signal=ADCx_IN7

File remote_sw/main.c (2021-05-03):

/**
  ******************************************************************************
  * @file    GPIO_Toggle\main.c
  * @author  MCD Application Team
  * @version V2.0.4
  * @date    26-April-2018
  * @brief   This file contains the main function for GPIO Toggle example.
  ******************************************************************************
  * @attention
  *
  * <h2><center>&copy; COPYRIGHT 2014 STMicroelectronics</center></h2>
  *
  * Licensed under MCD-ST Liberty SW License Agreement V2, (the "License");
  * You may not use this file except in compliance with the License.
  * You may obtain a copy of the License at:
  *
  *        http://www.st.com/software_license_agreement_liberty_v2
  *
  * Unless required by applicable law or agreed to in writing, software 
  * distributed under the License is distributed on an "AS IS" BASIS, 
  * WITHOUT WARRANTIES OR CONDITIONS OF ANY KIND, either express or implied.
  * See the License for the specific language governing permissions and
  * limitations under the License.
  *
  ******************************************************************************
  */

/* Includes ------------------------------------------------------------------*/
#include "main.h"
#include "SSD1306.h"
#include "MPU6050.h"

/**
  * @addtogroup GPIO_Toggle
  * @{
  */

/* Private typedef -----------------------------------------------------------*/
/* Private define ------------------------------------------------------------*/
/* Evalboard I/Os configuration */
/* Private macro -------------------------------------------------------------*/
/* Private variables ---------------------------------------------------------*/
extern struct MPU6050 mpu6050;
/* Private function prototypes -----------------------------------------------*/
void Delay(uint16_t nCount);
void BT_Send(uint8_t *, uint8_t);
/* Private functions ---------------------------------------------------------*/

void initPeripherals();

/* Public functions ----------------------------------------------------------*/

/**
  * @brief  Main program.
  * @param  None
  * @retval None
  */
void main(void)
{
  initPeripherals();

  uint8_t tick = 0;
  uint8_t mode = 0;
  uint8_t topStart = 0;
  uint8_t topped = 0;
  while (1)
  {
    uint8_t top = !GPIO_ReadInputPin(TOP_BUTTON_GPIO_PORT, TOP_BUTTON_GPIO_PIN);
    uint8_t side = !GPIO_ReadInputPin(SIDE_BUTTON_GPIO_PORT, SIDE_BUTTON_GPIO_PIN);

    if (tick % 10 == 0)
    {
      GPIO_WriteReverse(LED0_GPIO_PORT, LED0_GPIO_PIN);

      if (top)
      {
        if (!topped)
          topStart = tick;
        topped = 1;
      }
      else if (topped)
      {
        topped = 0;
        if (tick - topStart < 20)
          mode = mode ? 0 : 1;
      }

      if (top == mode || side)
      {
        uint16_t volt = (uint16_t)((uint32_t)100 * ADC1_GetConversionValue() * 4 / 696);

        clearDisplay();
        drawString(0, 0, "ti", 2);
        drawUint16(24, 0, tick);
        drawString(0, 8, "vo", 2);
        drawUint16(24, 8, volt);
        drawUint16(0, 16, mpu6050.buffer[0]);
        drawUint16(64, 16, mpu6050.buffer[1]);

        drawUint16(72, 0, mpu6050.who_am_i);

        if (volt < 360)
          drawString(0, 24, "LOW BATT", 8);
        if (top)
          drawString(54, 24, "TOP", 3);
        if (side)
          drawString(78, 24, "SIDE", 4);

        display();
      }
    }

    mpu6050_readData();
    for (uint8_t i = 0; i < 2; ++i)
    {
      BT_Send("123", 3);
      BT_Send(mpu6050.buffer, 14);
      BT_Send(&top, 1);
      BT_Send(&side, 1);
      BT_Send("456", 3);
    }

    tick += 1;
  }
}

void initPeripherals()
{
  // wait for clock to settle
  for (uint16_t i = 0; i < 0xffff; ++i)
    ;

  disableInterrupts();

  // clk init
  CLK->ICKR = CLK_ICKR_RESET_VALUE;
  CLK->ECKR = CLK_ECKR_RESET_VALUE;
  CLK->SWR = CLK_SWR_RESET_VALUE;
  CLK->SWCR = CLK_SWCR_RESET_VALUE;
  CLK->CKDIVR = CLK_CKDIVR_RESET_VALUE;
  CLK->PCKENR1 = CLK_PCKENR1_RESET_VALUE;
  CLK->PCKENR2 = CLK_PCKENR2_RESET_VALUE;
  CLK->CSSR = CLK_CSSR_RESET_VALUE;
  CLK->CCOR = CLK_CCOR_RESET_VALUE;
  while ((CLK->CCOR & CLK_CCOR_CCOEN) != 0)
    ;
  CLK->CCOR = CLK_CCOR_RESET_VALUE;
  CLK->HSITRIMR = CLK_HSITRIMR_RESET_VALUE;
  CLK->SWIMCCR = CLK_SWIMCCR_RESET_VALUE;
  CLK->CKDIVR &= (uint8_t)(~CLK_CKDIVR_HSIDIV);
  CLK->CKDIVR |= (uint8_t)0;

  // gpio init
  GPIO_Init(TOP_BUTTON_GPIO_PORT, TOP_BUTTON_GPIO_PIN, GPIO_MODE_IN_FL_NO_IT);
  GPIO_Init(SIDE_BUTTON_GPIO_PORT, SIDE_BUTTON_GPIO_PIN, GPIO_MODE_IN_FL_NO_IT);
  GPIO_Init(LED0_GPIO_PORT, LED0_GPIO_PIN, GPIO_MODE_OUT_PP_LOW_FAST);

  // i2c init
  GPIO_Init(SCL_GPIO_PORT, SCL_GPIO_PIN, GPIO_MODE_OUT_OD_HIZ_FAST);
  GPIO_Init(SDA_GPIO_PORT, SDA_GPIO_PIN, GPIO_MODE_OUT_OD_HIZ_FAST);

  // uart
  UART1_DeInit();
  UART1_Init(38400, UART1_WORDLENGTH_8D, UART1_STOPBITS_1, UART1_PARITY_NO,
             (UART1_SyncMode_TypeDef)(UART1_SYNCMODE_CLOCK_ENABLE | UART1_SYNCMODE_CPOL_LOW | UART1_SYNCMODE_CPHA_MIDDLE | UART1_SYNCMODE_LASTBIT_ENABLE),
             UART1_MODE_TXRX_ENABLE);
  UART1_Cmd(ENABLE);

  // ssd1306
  ssd1306_begin();
  clearDisplay();

  // mpu6050
  mpu6050_begin();

  // adc1
  ADC1_DeInit();
  ADC1_Init(ADC1_CONVERSIONMODE_CONTINUOUS, ADC1_CHANNEL_4, ADC1_PRESSEL_FCPU_D8,
            ADC1_EXTTRIG_TIM, DISABLE, ADC1_ALIGN_RIGHT, ADC1_SCHMITTTRIG_CHANNEL4,
            DISABLE);
  ADC1_StartConversion();

  enableInterrupts();
}

/**
  * @brief Delay
  * @param nCount
  * @retval None
  */
void Delay(uint16_t nCount)
{
  /* Decrement nCount value */
  while (nCount != 0)
  {
    nCount--;
  }
}

void BT_Send(uint8_t *data, uint8_t n)
{
  for (uint8_t i = 0; i < n; ++i)
  {
    while (!((UART1->SR & (uint8_t)UART1_FLAG_TXE) != (uint8_t)0x00))
    {
    }
    UART1_SendData8(data[i]);
  }
}

#ifdef USE_FULL_ASSERT

/**
  * @brief  Reports the name of the source file and the source line number
  *   where the assert_param error has occurred.
  * @param file: pointer to the source file name
  * @param line: assert_param error line source number
  * @retval None
  */
void assert_failed(uint8_t *file, uint32_t line)
{
  /* User can add his own implementation to report the file name and line number,
     ex: printf("Wrong parameters value: file %s on line %d\r\n", file, line) */

  /* Infinite loop */
  while (1)
  {
  }
}
#endif

/**
  * @}
  */

/************************ (C) COPYRIGHT STMicroelectronics *****END OF FILE****/

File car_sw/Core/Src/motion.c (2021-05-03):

/*
 * motion.c
 *
 *  Created on: Apr 16, 2021
 *      Author: jasoni111
 */
#define PI 3.141592654
#include "motion.h"
#include "DRV8801.h"
#include "math.h"
//#include "usart.h"
#include "blue.h"
#include <stdlib.h>

typedef struct MotorDirAndSpeed {
	int motor0Dir;
	float motor0Speed;
	int motor1Dir;
	float motor1Speed;
	int motor2Dir;
	float motor2Speed;
} MotorDirAndSpeed;

MotorDirAndSpeed storedDirAndSpeed = { 0, 0, 0, 0, 0, 0 };

/**
 *
 */
MotorDirAndSpeed getMotorDirAndSpeed(float x, float y, float w) {
	MotorDirAndSpeed dirAndSpeed;
	int d = 1;
	dirAndSpeed.motor0Speed = w * d + x;
	dirAndSpeed.motor1Speed = w * d - x / 2 - y * sin(PI / 3);
	dirAndSpeed.motor2Speed = w * d - x / 2 + y * sin(PI / 3);

	dirAndSpeed.motor0Dir = dirAndSpeed.motor0Speed > 0;
	dirAndSpeed.motor1Dir = dirAndSpeed.motor1Speed > 0;
	dirAndSpeed.motor2Dir = dirAndSpeed.motor2Speed > 0;
	dirAndSpeed.motor0Speed = abs(dirAndSpeed.motor0Speed);
	dirAndSpeed.motor1Speed = abs(dirAndSpeed.motor1Speed);
	dirAndSpeed.motor2Speed = abs(dirAndSpeed.motor2Speed);

	return dirAndSpeed;
}

void move(Direction dir) {
	float x, y, w = 0;

	switch (dir) {
	case MOTION_FORWARD: {
		x = 12;
		y = 0;
		w = 0;
		break;
	}
	case MOTION_BACKWARD: {
		x = -12;
		y = 0;
		w = 0;
		break;
	}
	case MOTION_TRANSLATE_LEFT: {
		x = 0;
		y = 12;
		w = 0;
		break;
	}
	case MOTION_TRANSLATE_RIGHT: {
		x = 0;
		y = -12;
		w = 0;
		break;
	}
	case MOTION_ROTATE_LEFT: {
		x = 0;
		y = 0;
		w = 8;
		break;
	}
	case MOTION_ROTATE_RIGHT: {
		x = 0;
		y = 0;
		w = -8;
		break;
	}
	case MOTION_STOP: {
		x = 0;
		y = 0;
		w = 0;
		break;
	}
	default: {
		x = 0;
		y = 0;
		w = 0;
		break;
	}
	}
	storedDirAndSpeed = getMotorDirAndSpeed(x, y, w);
}

void MotorUpdate() {
	static last_tick = 0;
	uint32_t tick = HAL_GetTick();
	uint32_t dt = tick - last_tick;
	if (dt < 10) {
		return;
	}

	char c[20];
	sendfloat(0, 12.0f);


	static float I_error[3] = { 0, 0, 0 };
	static uint32_t power_value[3] = { 0, 0, 0 };
	int dir[3] = { storedDirAndSpeed.motor0Dir, storedDirAndSpeed.motor1Dir,
			storedDirAndSpeed.motor2Dir };
	float target_speed[3] = { storedDirAndSpeed.motor0Speed,
			storedDirAndSpeed.motor1Speed, storedDirAndSpeed.motor2Speed };
	float last_error[3] = { 0, 0, 0 };

	for (uint8_t i = 0; i < 3; ++i) {

		float speed = (float) getCount(i) / dt * 100.0;

		float error = (float) target_speed[i] - speed;
		I_error[i] = I_error[i] + error;
		if (speed < 1) {
			I_error[i] += error*4;
		}

		sendfloat(10 + i, speed);

		if (target_speed[i] == 0) {
			I_error[i] = 0;
			power_value[i] = 0;
			setPower(i, power_value[i]);
			continue;
		}

		if (target_speed[i] == 0) {
			I_error[i] = 0;
			power_value[i] = 0;
			setPower(i, power_value[i]);
			continue;
		}
		float derror = last_error[i] - error;

		int p = (error * 35 * (5+target_speed[i])/target_speed[i] + I_error[i] * 8 + derror * 3);
		power_value[i] = p > 0 ? p : 0;

		last_error[i] = error;
		setDirection(i, dir[i]);
		setPower(i, power_value[i]);

	}
	last_tick = tick;

}

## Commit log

2021-04-01 feat: init hardware
    [IR.sch, Motor.sch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]
2021-04-11 feat: cat motor & encoder work
2021-04-13 feat: car mech update motor mount
2021-04-14 feat: car sw motor ready
2021-04-14 fix: car sw clean up
    [DRV8801.c]
2021-04-30 feat: 8051 soft i2c
2021-04-30 feat: remote sw soft i2c, lcd ready
2021-05-01 feat: top button
2021-05-01 feat: buggy toggle mode
    [main.c]
2021-05-01 added blue, pid, working on MPU6050
2021-05-03 feat: fix remote delay time
    [main.c]
2021-12-29 chore: change 3D print previews to png

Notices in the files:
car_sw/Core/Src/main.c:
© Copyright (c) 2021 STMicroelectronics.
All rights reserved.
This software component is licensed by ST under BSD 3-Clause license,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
